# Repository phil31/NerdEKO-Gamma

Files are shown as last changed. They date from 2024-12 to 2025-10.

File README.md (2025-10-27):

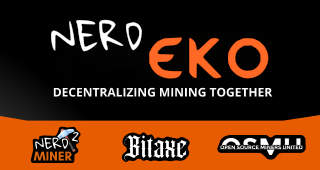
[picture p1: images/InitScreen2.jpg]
Nerd_EKO


# Nerd-EKO-Gamma Miner

fork of the NerdOCTAXE-Gamma design (https://github.com/Patsch91/NerdOCTAXE-Gamma), with 12 x BM1370 (14TH/s SHA256)
	
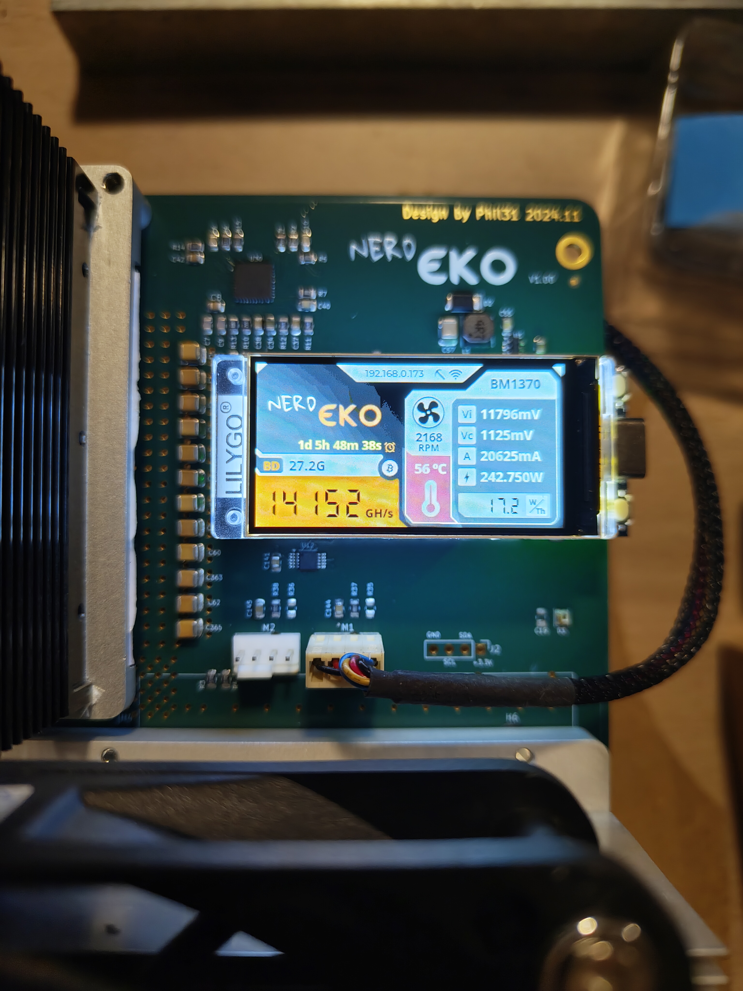
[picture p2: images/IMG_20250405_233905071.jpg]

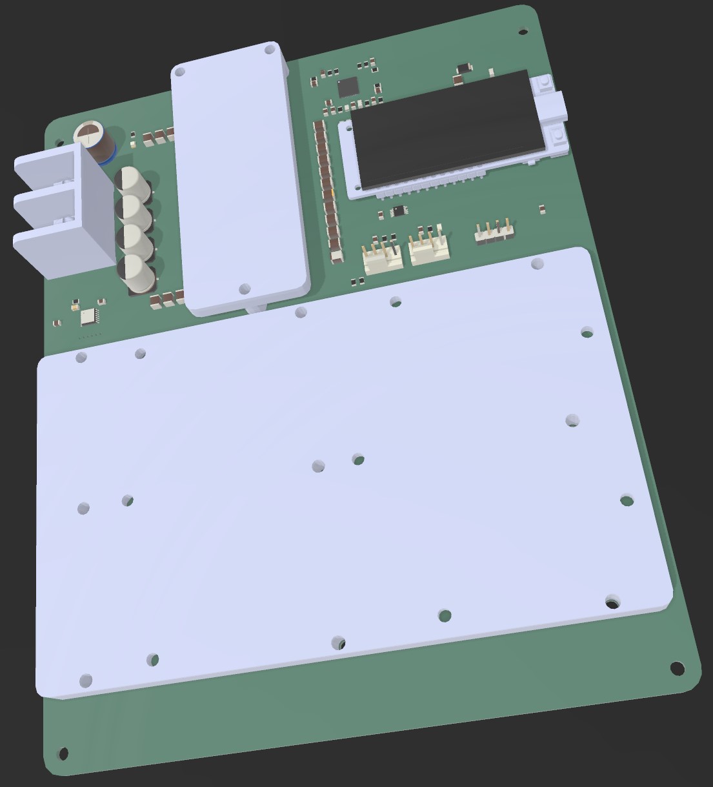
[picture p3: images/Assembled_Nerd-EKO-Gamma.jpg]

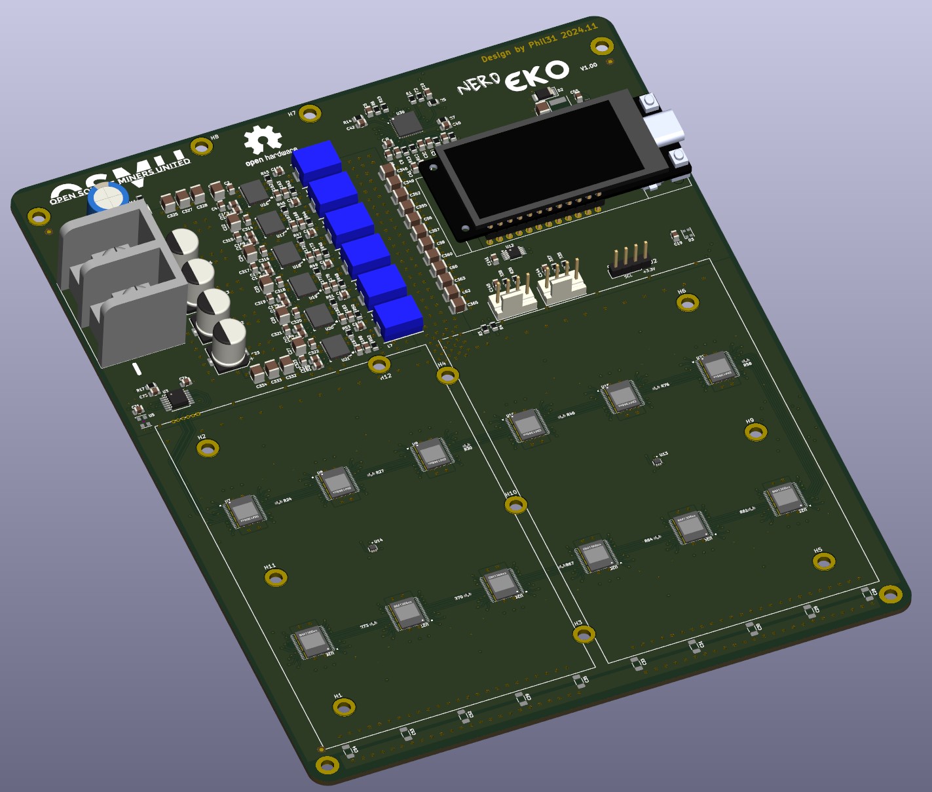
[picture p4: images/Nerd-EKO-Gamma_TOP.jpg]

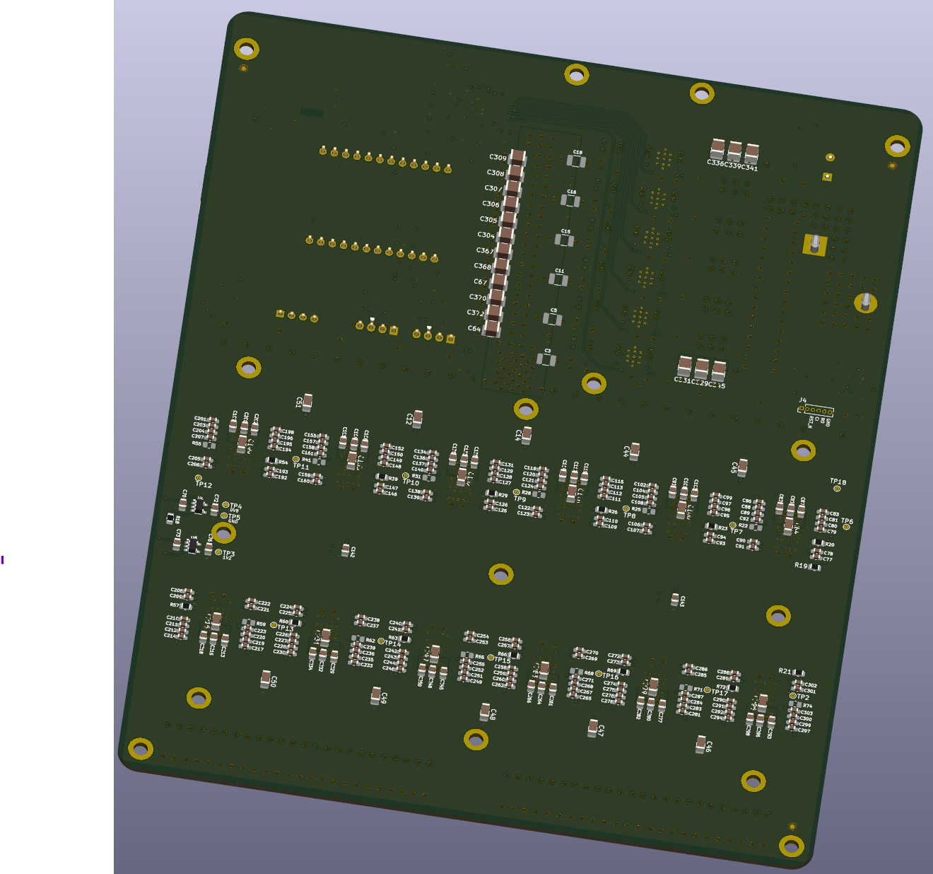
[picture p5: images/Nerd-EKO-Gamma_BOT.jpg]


- 6 layers PCB - Outer / Inner Copper Weight: 2 oz

Design fully tested and validated
consume about 230 Watts on 12V for about 14TH/s (Vcore 1100mV, Icore 180A)
use a 12V 40A PSU

be aware, need some knowledge and tools to build this board !
particulary attention : NEVER power up the board with the Vcore enable without proper heatsink (this will immediatly kill the ASICs !)

## License 
This hardware design is licensed under the TAPR Open Hardware License – Non-Commercial (OHL-NC).  
You are free to use, modify, and distribute for **non-commercial purposes**.  

**Commercial use requires explicit written permission from the copyright holder.**  
See the [LICENSE](LICENSE) file for details.

## Inspired by 
[Bitaxe](https://github.com/skot/bitaxe) 
[NerdAxe](https://github.com/BitMaker-hub)
[NerdOCTAXE](https://github.com/Patsch91/NerdOCTAXE-Gamma) 
[ESP-Miner-NerdQAxePlus](https://github.com/shufps/ESP-Miner-NerdQAxePlus)
[OSMU](https://osmu.wiki/)

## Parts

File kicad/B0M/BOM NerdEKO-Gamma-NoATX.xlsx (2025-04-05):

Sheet: BOM NerdEKO-Gamma-NoATX (2)
Reference | Value | Footprint | Qty | DNP | P/N MOUSER | P/N LCSC
C77,C78,C79,C80,C81,C83,C86,C88,C89,C90,C91,C92,C93,C94,C95,C96,C97,C99,C102,C104,C105,C106,C107,C108,C109,C110,C111,C112,C113,C115,C118,C120,C121,C122,C123,C124,C125,C126,C127,C128,C129,C131,C134,C136,C137,C138,C139,C140,C146,C147,C148,C149,C150,C152,C155,C157,C158,C159,C160,C161,C192,C193,C194,C195,C196,C198,C201,C203,C204,C205,C206,C207,C208,C209,C210,C211,C212,C214,C217,C219,C220,C221,C222,C223,C224,C225,C226,C227,C228,C230,C233,C235,C236,C237,C238,C239,C240,C241,C242,C243,C244,C246,C249,C251,C252,C253,C254,C255,C256,C257,C258,C259,C260,C262,C265,C267,C268,C269,C270,C271,C272,C273,C274,C275,C276,C278,C281,C283,C284,C285,C286,C287,C288,C289,C290,C291,C292,C294,C297,C299,C300,C301,C302,C303 | 1µF/6.3V | Capacitor_SMD:C_0603_1608Metric_Pad1.08x0.95mm_HandSolder | 144 |  | 187-CL10A105KQ8NNNC | C105524
C2,C19,C21,C70,C71,C73,C74,C75,C87,C103,C119,C135,C141,C142,C143,C144,C145,C156,C162,C164,C167,C169,C172,C174,C177,C179,C182,C184,C187,C189,C202,C218,C234,C250,C266,C282,C298,C314,C316,C318,C320,C322 | 100nF | Capacitor_SMD:C_0805_2012Metric | 42 |  | 791-0805B104M101CT | C476766
C4,C37,C38,C72,C76,C85,C101,C117,C133,C154,C200,C216,C232,C248,C264,C280,C296,C315,C317,C319,C321,C323 | 1µF/25V | Capacitor_SMD:C_0805_2012Metric | 22 |  | 187-CL21B105KAFNNNE | C344171
C6,C10,C43,C165,C166,C170,C171,C175,C176,C180,C181,C185,C186,C190,C191 | 1nF | Capacitor_SMD:C_0805_2012Metric | 15 |  | 603-CC805KRX7R0BB102 | C106244
C7,C9 | 22pF | Capacitor_SMD:C_0805_2012Metric | 2 |  | 187-CL21C220JBANNNC | C1804
C8 | 100pF | Capacitor_SMD:C_0805_2012Metric | 1 |  | 791-0805B101M250CT | C3897824
C13,C17,C82,C98,C114,C130,C151,C197,C213,C229,C245,C261,C277,C293 | 10µF/25V | Capacitor_SMD:C_0805_2012Metric | 14 |  | 963-TMK212BBJ106MG-T | C6119887
C34 | 4.7µF/16V | Capacitor_SMD:C_0805_2012Metric | 1 |  | 187-CL21A475KOFNNNG | C22399642
C40 | 330nF | Capacitor_SMD:C_0805_2012Metric | 1 |  | 187-CL21B334KBFNNNE | C73142
C41 | 12pF | Capacitor_SMD:C_0805_2012Metric | 1 |  | 581-KGM15ACG2A120JM | C20218205
C42 | 2.2nF | Capacitor_SMD:C_0805_2012Metric | 1 |  | 791-0805B222K160CT | C3907092
C55 | 10nF | Capacitor_SMD:C_0805_2012Metric | 1 |  | 187-CL21B103KBANNNC | C1710
C163,C168,C173,C178,C183,C188 | 2.2µF/16V | Capacitor_SMD:C_0805_2012Metric | 6 |  | 187-CL21A225KOFNNNE | C5448893
C12,C14,C44,C45,C46,C47,C48,C49,C50,C51,C84,C100,C116,C132,C153,C199,C215,C231,C247,C263,C279,C295 | 100µ/6.3V | Capacitor_SMD:C_1206_3216Metric | 22 |  | 187-CL31A107MQHNNWE | C15008
C28,C29,C30,C31,C33,C35,C39,C52,C53,C54 | 100µ/6.3V | Capacitor_SMD:C_1206_3216Metric | 10 | DNP | 187-CL31A107MQHNNWE | C15008
C3,C5,C11,C15,C16,C18 | 330µF/4V | Capacitor_SMD:C_1210_3225Metric | 6 | DNP | 81-GRM32ER60G337ME5K | C528969
C20,C22,C24,C25,C26,C27,C57,C325,C327,C328,C329,C331,C332,C333,C334,C336,C339,C341,C345 | 22µ/25V | Capacitor_SMD:C_1210_3225Metric | 19 |  | 187-CL32A226KAJNNNE | C52306
C56,C58,C60,C62,C64,C67,C304,C305,C306,C307,C308,C309,C346,C349,C352,C355,C357,C360,C363,C365,C367,C368,C370,C372 | 330µF/4V | Capacitor_SMD:C_1210_3225Metric | 24 |  | 81-GRM32ER60G337ME5K | C528969
C23,C32,C36,C313 | 470µ/25V | Capacitor_SMD:CP_Elec_8x10 | 4 |  | 647-UWT1E471MNL1S | C4054389
C1 | 1000uF/25V | Capacitor_THT:CP_Radial_D10.0mm_P5.00mm | 1 |  | 667-EEU-FR1E102L | C2980548
M1,M2 | Fan_4pin | Connector:FanPinHeader_1x04_P2.54mm_Vertical | 2 |  | 538-47053-1000 | C240840
J2 | Conn_01x04 | Connector_PinHeader_2.54mm:PinHeader_1x04_P2.54mm_Vertical | 1 | DNP
D2 | PMEG4030EP,115 | Diode_SMD:D_SOD-128 | 1 |  | 771-PMEG4030EP-QX | C96234
U7,U8,U9,U10,U15,U22,U23,U24,U25,U26,U27,U28 | BM1370_mode1 | EKO_Miner_ASIClib:BM1370 | 12
U16,U17,U18,U19,U20,U21 | CSD95472Q5MC | EKO_Miner_ASIClib:CSD95472Q5MC | 6 |  | 595-CSD95472Q5MC | C1880674
L2,L3,L4,L5,L6,L7 | 220nH | EKO_Miner_ASIClib:INDM1031X765N | 6 |  | 504-FP1008R5-R220-R | C2639748
U11 | T-Display-S3 | EKO_Miner_ASIClib:LILYGO Tdisplay S3 | 1
J1 | Conn_01x02 | EKO_Miner_ASIClib:MOLEX_38969-0002 | 1 |  | 538-38969-0002 | C7426780
U13,U14 | TMP1075NDRLR | EKO_Miner_ASIClib:SOT50P160X60-6N | 2 |  | 595-TMP1075NDRLR | C3663690
U30 | TPS53667RTAR | EKO_Miner_ASIClib:TPS53667RTAR | 1 |  | 595-TPS53667RTAT | C702270
L1 | 4.7µH | Inductor_SMD:L_Taiyo-Yuden_NR-50xx | 1 |  | 710-74404052047 | C703747
D1 | LED | LED_SMD:LED_0805_2012Metric_Pad1.15x1.40mm_HandSolder | 1 |  | 859-LTST-C171GKT | C913075
D3 | WS2812B-2020 | LED_SMD:LED_WS2812B-2020_PLCC4_2.0x2.0mm | 1 |  | 485-4684 | C965555
U5 | 25MHz | Oscillator:Oscillator_SMD_EuroQuartz_XO32-4Pin_3.2x2.5mm | 1 |  | 449-LFSPXO076024CUTT | C17671752
U12 | EMC2302-1 | Package_SO:MSOP-10_3x3mm_P0.5mm | 1 |  | 886-EMC2302-1-AIZLTR | C626969
U3 | TXU0304PW | Package_SO:TSSOP-14-1EP_4.4x5mm_P0.65mm | 1 |  | 595-TXU0304PWR | C4364118
U4 | MCP1824T-0802E | Package_TO_SOT_SMD:SOT-23-5 | 1 |  | 579-MCP1824T-0802EOT | C625460
U6 | MCP1824T-1202E | Package_TO_SOT_SMD:SOT-23-5 | 1 |  | 579-MCP1824T-1202EOT | C625461
U1 | AP3211 | Package_TO_SOT_SMD:SOT-23-6 | 1 |  | 621-AP3211KTR-G1 | C154863
R24,R27,R30,R40,R58,R61,R64,R67,R70,R73,R76 | 33R | Resistor_SMD:R_0402_1005Metric_Pad0.72x0.64mm_HandSolder | 11 |  | 652-CR0402FX-33R0GLF | C102986
R1,R9 | 16.5K | Resistor_SMD:R_0805_2012Metric | 2 |  | 603-RC0805FR-0716K5L | C35929
R2 | 24.3K | Resistor_SMD:R_0805_2012Metric | 1 |  | 603-RC0805FR-0724K3L | C17569
R3,R4 | 51 0.5% | Resistor_SMD:R_0805_2012Metric | 2 |  | 603-RT0805DRE0751RL | C868849
R5,R7,R17,R18,R19,R21,R32,R35,R36 | 10K | Resistor_SMD:R_0805_2012Metric | 9 |  | 279-CRGCQ0805F10K | C84376
R6 | 121K | Resistor_SMD:R_0805_2012Metric | 1 |  | 603-RT0805FRE07121KL | C17438
R8 | 86.6K | Resistor_SMD:R_0805_2012Metric | 1 |  | 652-CR0805FX-8662ELF | C17846
R10 | 2.55K | Resistor_SMD:R_0805_2012Metric | 1 |  | 667-ERJ-P06F2551V | C2933383
R11,R12 | 2.2R | Resistor_SMD:R_0805_2012Metric | 2 |  | 708-RMCF0805FT2R20 | C17521
R13 | 8.06K | Resistor_SMD:R_0805_2012Metric | 1 |  | 603-RC0805FR-078K06L | C2933501
R14 | 33.2K | Resistor_SMD:R_0805_2012Metric | 1 |  | 708-RMCF0805FT33K2 | C3016779
R15 | 100K | Resistor_SMD:R_0805_2012Metric | 1 |  | 279-CRG0805F100K | C149504
R16,R20,R23,R26,R29,R39,R54,R57,R60,R63,R66,R69,R72 | 1K | Resistor_SMD:R_0805_2012Metric | 13 |  | 708-RNCP0805FTD1K00 | C17513
R22,R25,R28,R31,R41,R56,R59,R62,R65,R68,R71,R74 | 2K | Resistor_SMD:R_0805_2012Metric | 12 | DNP | 652-CR0805FX-2001ELF | C17604
R33,R34 | 10K | Resistor_SMD:R_0805_2012Metric | 2 | DNP | 279-CRGCQ0805F10K | C84376
R37,R38 | 2.7K | Resistor_SMD:R_0805_2012Metric | 2 |  | 652-CR0805FX-2701ELF | C2907236
R42,R43,R44,R45,R46,R47,R48,R49,R50,R51,R52,R53 | 1R | Resistor_SMD:R_0805_2012Metric | 12 |  | 791-WR08W1R00FTL | C163970
TP2,TP3,TP4,TP5,TP6,TP7,TP8,TP9,TP10,TP11,TP12,TP13,TP14,TP15,TP16,TP17,TP18 | TestPoint | TestPoint:TestPoint_Pad_D1.0mm | 17 | DNP

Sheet: BOM NerdEKO-Gamma-NoATX
Reference,"Value","Footprint","Qty","DNP","P/N MOUSER","P/N LCSC"
C77,C78,C79,C80,C81,C83,C86,C88,C89,C90,C91,C92,C93,C94,C95,C96,C97,C99,C102,C104,C105,C106,C107,C108,C109,C110,C111,C112,C113,C115,C118,C120,C121,C122,C123,C124,C125,C126,C127,C128,C129,C131,C134,C136,C137,C138,C139,C140,C146,C147,C148,C149,C150,C152,C155,C157,C158,C159,C160,C161,C192,C193,C194,C195,C196,C198,C201,C203,C204,C205,C206,C207,C208,C209,C210,C211,C212,C214,C217,C219,C220,C221,C222,C223,C224,C225,C226,C227,C228,C230,C233,C235,C236,C237,C238,C239,C240,C241,C242,C243,C244,C246,C249,C251,C252,C253,C254,C255,C256,C257,C258,C259,C260,C262,C265,C267,C268,C269,C270,C271,C272,C273,C274,C275,C276,C278,C281,C283,C284,C285,C286,C287,C288,C289,C290,C291,C292,C294,C297,C299,C300,C301,C302,C303,"1ÂµF/6.3V","Capacitor_SMD:C_0603_1608Metric_Pad1.08x0.95mm_HandSolder","144","","187-CL10A105KQ8NNNC","C105524"
C2,C19,C21,C70,C71,C73,C74,C75,C87,C103,C119,C135,C141,C142,C143,C144,C145,C156,C162,C164,C167,C169,C172,C174,C177,C179,C182,C184,C187,C189,C202,C218,C234,C250,C266,C282,C298,C314,C316,C318,C320,C322,"100nF","Capacitor_SMD:C_0805_2012Metric","42","","791-0805B104M101CT","C476766"
C4,C37,C38,C72,C76,C85,C101,C117,C133,C154,C200,C216,C232,C248,C264,C280,C296,C315,C317,C319,C321,C323,"1ÂµF/25V","Capacitor_SMD:C_0805_2012Metric","22","","187-CL21B105KAFNNNE","C344171"
C6,C10,C43,C165,C166,C170,C171,C175,C176,C180,C181,C185,C186,C190,C191,"1nF","Capacitor_SMD:C_0805_2012Metric","15","","603-CC805KRX7R0BB102","C106244"
C7,C9,"22pF","Capacitor_SMD:C_0805_2012Metric","2","","187-CL21C220JBANNNC","C1804"
C8,"100pF","Capacitor_SMD:C_0805_2012Metric","1","","791-0805B101M250CT","C3897824"
C13,C17,C82,C98,C114,C130,C151,C197,C213,C229,C245,C261,C277,C293,"10ÂµF/25V","Capacitor_SMD:C_0805_2012Metric","14","","963-TMK212BBJ106MG-T","C6119887"
C34,"4.7ÂµF/16V","Capacitor_SMD:C_0805_2012Metric","1","","187-CL21A475KOFNNNG","C22399642"
C40,"330nF","Capacitor_SMD:C_0805_2012Metric","1","","187-CL21B334KBFNNNE","C73142"
C41,"12pF","Capacitor_SMD:C_0805_2012Metric","1","","581-KGM15ACG2A120JM","C20218205"
C42,"2.2nF","Capacitor_SMD:C_0805_2012Metric","1","","791-0805B222K160CT","C3907092"
C55,"10nF","Capacitor_SMD:C_0805_2012Metric","1","","187-CL21B103KBANNNC","C1710"
C163,C168,C173,C178,C183,C188,"2.2ÂµF/16V","Capacitor_SMD:C_0805_2012Metric","6","","187-CL21A225KOFNNNE","C5448893"
C12,C14,C44,C45,C46,C47,C48,C49,C50,C51,C84,C100,C116,C132,C153,C199,C215,C231,C247,C263,C279,C295,"100Âµ/6.3V","Capacitor_SMD:C_1206_3216Metric","22","","187-CL31A107MQHNNWE","C15008"
C28,C29,C30,C31,C33,C35,C39,C52,C53,C54,"100Âµ/6.3V","Capacitor_SMD:C_1206_3216Metric","10","DNP","187-CL31A107MQHNNWE","C15008"
C3,C5,C11,C15,C16,C18,"330ÂµF/4V","Capacitor_SMD:C_1210_3225Metric","6","DNP","81-GRM32ER60G337ME5K","C528969"
C20,C22,C24,C25,C26,C27,C57,C325,C327,C328,C329,C331,C332,C333,C334,C336,C339,C341,C345,"22Âµ/25V","Capacitor_SMD:C_1210_3225Metric","19","","187-CL32A226KAJNNNE","C52306"
C56,C58,C60,C62,C64,C67,C304,C305,C306,C307,C308,C309,C346,C349,C352,C355,C357,C360,C363,C365,C367,C368,C370,C372,"330ÂµF/4V","Capacitor_SMD:C_1210_3225Metric","24","","81-GRM32ER60G337ME5K","C528969"
C23,C32,C36,C313,"470Âµ/25V","Capacitor_SMD:CP_Elec_8x10","4","","647-UWT1E471MNL1S","C4054389"
C1,"1000uF/25V","Capacitor_THT:CP_Radial_D10.0mm_P5.00mm","1","","667-EEU-FR1E102L","C2980548"
M1,M2,"Fan_4pin","Connector:FanPinHeader_1x04_P2.54mm_Vertical","2","","538-47053-1000","C240840"
J2,"Conn_01x04","Connector_PinHeader_2.54mm:PinHeader_1x04_P2.54mm_Vertical","1","DNP","",""
D2,"PMEG4030EP,115","Diode_SMD:D_SOD-128","1","","771-PMEG4030EP-QX","C96234"
U7,U8,U9,U10,U15,U22,U23,U24,U25,U26,U27,U28,"BM1370_mode1","EKO_Miner_ASIClib:BM1370","12","","",""
U16,U17,U18,U19,U20,U21,"CSD95472Q5MC","EKO_Miner_ASIClib:CSD95472Q5MC","6","","595-CSD95472Q5MC","C1880674"
L2,L3,L4,L5,L6,L7,"220nH","EKO_Miner_ASIClib:INDM1031X765N","6","","504-FP1008R5-R220-R","C2639748"
U11,"T-Display-S3","EKO_Miner_ASIClib:LILYGO Tdisplay S3","1","","",""
J1,"Conn_01x02","EKO_Miner_ASIClib:MOLEX_38969-0002","1","","538-38969-0002","C7426780"
U13,U14,"TMP1075NDRLR","EKO_Miner_ASIClib:SOT50P160X60-6N","2","","595-TMP1075NDRLR","C3663690"
U30,"TPS53667RTAR","EKO_Miner_ASIClib:TPS53667RTAR","1","","595-TPS53667RTAT","C702270"
L1,"4.7ÂµH","Inductor_SMD:L_Taiyo-Yuden_NR-50xx","1","","710-74404052047","C703747"
D1,"LED","LED_SMD:LED_0805_2012Metric_Pad1.15x1.40mm_HandSolder","1","","859-LTST-C171GKT","C913075"
D3,"WS2812B-2020","LED_SMD:LED_WS2812B-2020_PLCC4_2.0x2.0mm","1","","485-4684","C965555"
U5,"25MHz","Oscillator:Oscillator_SMD_EuroQuartz_XO32-4Pin_3.2x2.5mm","1","","449-LFSPXO076024CUTT","C17671752"
U12,"EMC2302-1","Package_SO:MSOP-10_3x3mm_P0.5mm","1","","886-EMC2302-1-AIZLTR","C626969"
U3,"TXU0304PW","Package_SO:TSSOP-14-1EP_4.4x5mm_P0.65mm","1","","595-TXU0304PWR","C4364118"
U4,"MCP1824T-0802E","Package_TO_SOT_SMD:SOT-23-5","1","","579-MCP1824T-0802EOT","C625460"
U6,"MCP1824T-1202E","Package_TO_SOT_SMD:SOT-23-5","1","","579-MCP1824T-1202EOT","C625461"
U1,"AP3211","Package_TO_SOT_SMD:SOT-23-6","1","","621-AP3211KTR-G1","C154863"
R24,R27,R30,R40,R58,R61,R64,R67,R70,R73,R76,"33R","Resistor_SMD:R_0402_1005Metric_Pad0.72x0.64mm_HandSolder","11","","652-CR0402FX-33R0GLF","C102986"
R1,R9,"16.5K","Resistor_SMD:R_0805_2012Metric","2","","603-RC0805FR-0716K5L","C35929"
R2,"24.3K","Resistor_SMD:R_0805_2012Metric","1","","603-RC0805FR-0724K3L","C17569"
R3,R4,"51 0.5%","Resistor_SMD:R_0805_2012Metric","2","","603-RT0805DRE0751RL","C868849"
R5,R7,R17,R18,R19,R21,R32,R35,R36,"10K","Resistor_SMD:R_0805_2012Metric","9","","279-CRGCQ0805F10K","C84376"
R6,"121K","Resistor_SMD:R_0805_2012Metric","1","","603-RT0805FRE07121KL","C17438"
R8,"86.6K","Resistor_SMD:R_0805_2012Metric","1","","652-CR0805FX-8662ELF","C17846"
R10,"2.55K","Resistor_SMD:R_0805_2012Metric","1","","667-ERJ-P06F2551V","C2933383"
R11,R12,"2.2R","Resistor_SMD:R_0805_2012Metric","2","","708-RMCF0805FT2R20","C17521"
R13,"8.06K","Resistor_SMD:R_0805_2012Metric","1","","603-RC0805FR-078K06L","C2933501"
R14,"33.2K","Resistor_SMD:R_0805_2012Metric","1","","708-RMCF0805FT33K2","C3016779"
R15,"100K","Resistor_SMD:R_0805_2012Metric","1","","279-CRG0805F100K ","C149504"
R16,R20,R23,R26,R29,R39,R54,R57,R60,R63,R66,R69,R72,"1K","Resistor_SMD:R_0805_2012Metric","13","","708-RNCP0805FTD1K00","C17513"
R22,R25,R28,R31,R41,R56,R59,R62,R65,R68,R71,R74,"2K","Resistor_SMD:R_0805_2012Metric","12","DNP","652-CR0805FX-2001ELF","C17604"
R33,R34,"10K","Resistor_SMD:R_0805_2012Metric","2","DNP","279-CRGCQ0805F10K","C84376"
R37,R38,"2.7K","Resistor_SMD:R_0805_2012Metric","2","","652-CR0805FX-2701ELF","C2907236"
R42,R43,R44,R45,R46,R47,R48,R49,R50,R51,R52,R53,"1R","Resistor_SMD:R_0805_2012Metric","12","","791-WR08W1R00FTL","C163970"
TP2,TP3,TP4,TP5,TP6,TP7,TP8,TP9,TP10,TP11,TP12,TP13,TP14,TP15,TP16,TP17,TP18,"TestPoint","TestPoint:TestPoint_Pad_D1.0mm","17","DNP","",""

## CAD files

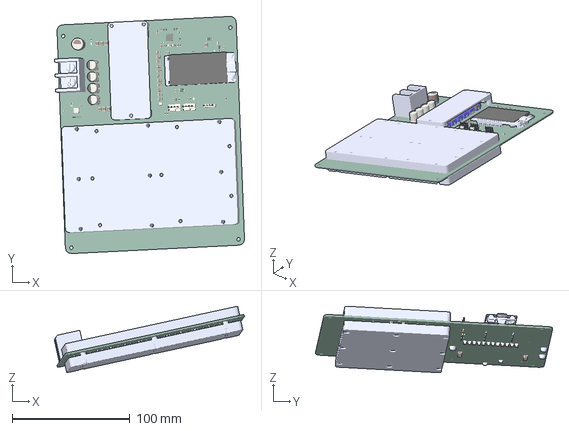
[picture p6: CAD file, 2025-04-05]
3D/Assemblage NerdEKO V1.0 with Heatsinks.3MF
161.3 x 201.3 x 56.3 mm

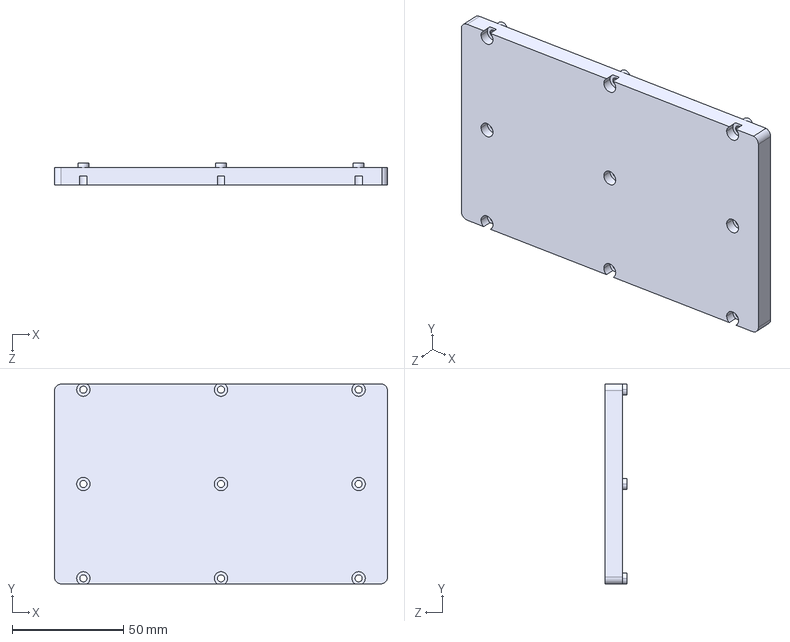
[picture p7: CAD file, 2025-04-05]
3D/EKO_Miner NerdEKO V1.0/Heatsink Nerd EKO - bottom ASICs V1.0.STEP
150.0 x 90.0 x 10.0 mm

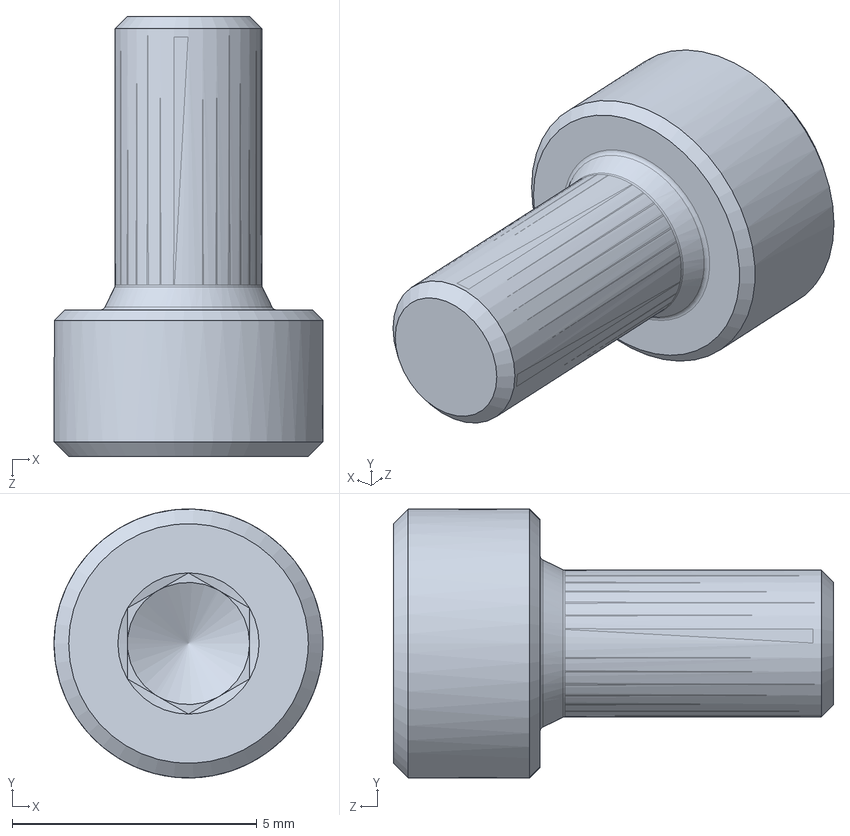
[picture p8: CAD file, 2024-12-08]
3D/quincaillerie/CHC3 M3x6mm.SLDPRT
5.50 x 5.50 x 9.00 mm

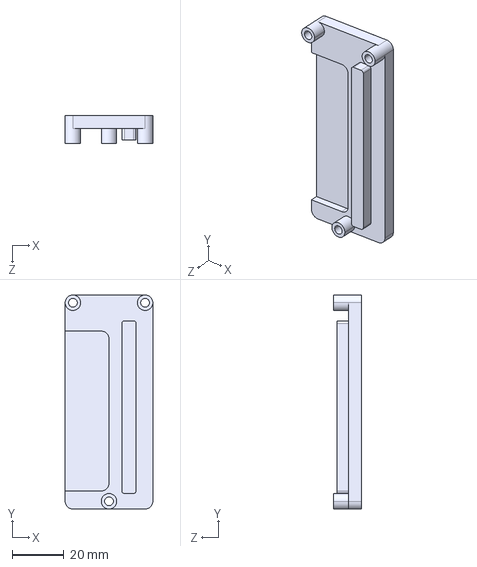
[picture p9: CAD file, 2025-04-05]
3D/EKO_Miner NerdEKO V1.0/Heatsink Nerd EKO - PSU V1.0.STEP
34.0 x 83.0 x 10.8 mm

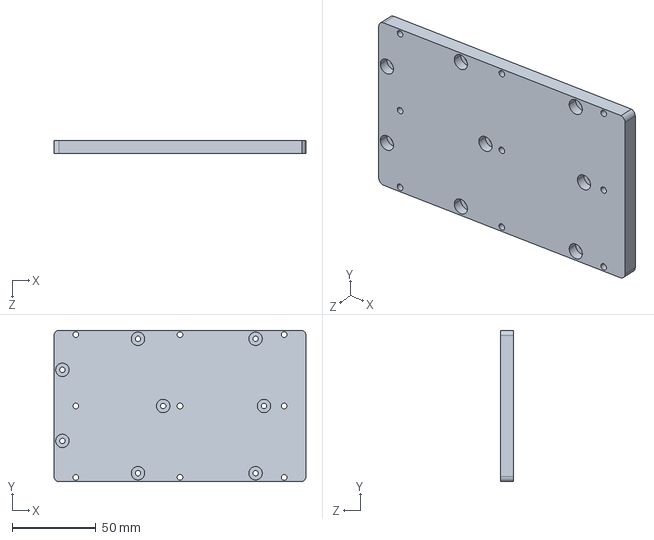
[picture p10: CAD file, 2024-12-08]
3D/EKO_Miner NerdEKO V1.0/Heatsink Nerd EKO - base ASICs V1.0.STEP
150.0 x 90.0 x 8.00 mm

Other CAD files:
3D/EKO_Miner NerdEKO V1.0/Heatsink Nerd EKO - PSU V1.0.SLDPRT
3D/EKO_Miner NerdEKO V1.0/Heatsink Nerd EKO - base ASICs V1.0.SLDPRT
3D/EKO_Miner NerdEKO V1.0/Heatsink Nerd EKO - bottom ASICs V1.0.SLDPRT

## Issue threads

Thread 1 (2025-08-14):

how to up 600Mhz

chenyang2151, 2025-08-14:
[

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

only 400mhz is the best，set uppon will 0v](url)

chenyang2151, 2025-08-14:
分析下具体会是什么原因导致的，非常感谢！爱你
参考知识
41/5000
Sorry, I was a bit anxious when I sent it. Could you please help me analyze the specific cause? Thank you very much! Love You

chenyang2151, 2025-08-14:
Sorry, I was a bit anxious when I sent it. Could you please help me analyze the specific cause? Thank you very much! Love You

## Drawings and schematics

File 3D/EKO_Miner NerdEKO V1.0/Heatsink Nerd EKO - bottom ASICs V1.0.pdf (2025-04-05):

E E

F F

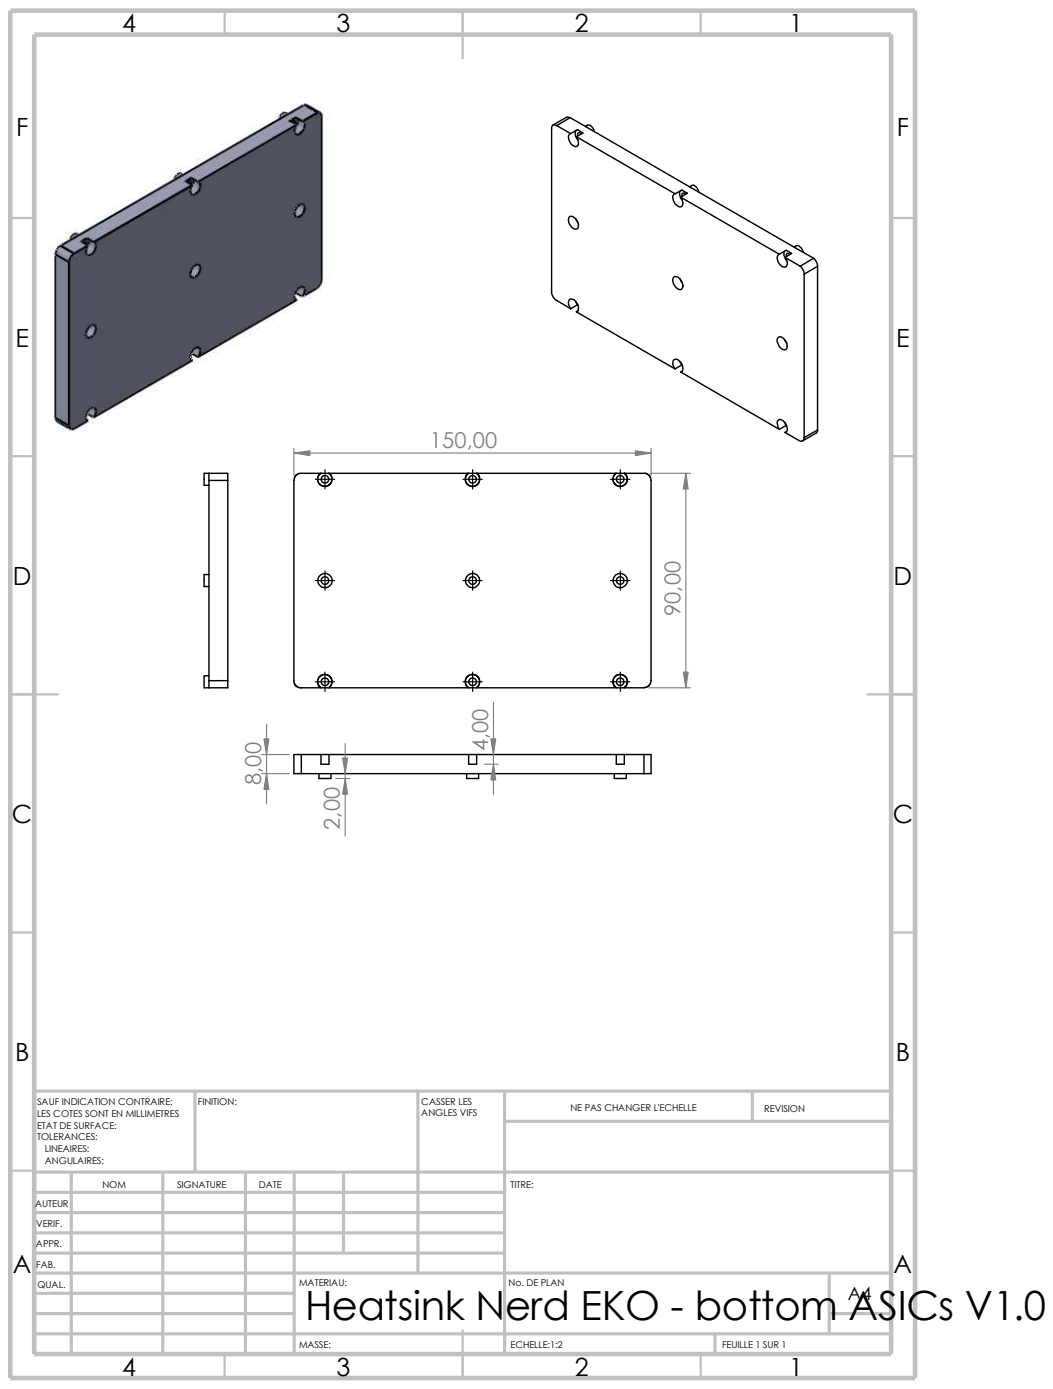
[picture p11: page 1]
MASSE:; FAB.; QUAL.; No. DE PLAN; ECHELLE:1:2; FEUILLE 1 SUR 1; FINITION:; ANGLES VIFS; MATERIAU:; NE PAS CHANGER L'ECHELLE; REVISION; CASSER LES; Heatsink Nerd EKO - bottom ASICs V1.0 ²,00 8,00

SAUF INDICATION CONTRAIRE:
LES COTES SONT EN MILLIMETRES
ETAT DE SURFACE:
TOLERANCES:
LINEAIRES:
ANGULAIRES:

NOM | SIGNATURE | DATE | TITRE:

AUTEUR
VERIF.
APPR.

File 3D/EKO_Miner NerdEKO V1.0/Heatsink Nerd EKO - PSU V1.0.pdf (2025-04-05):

E E

F F

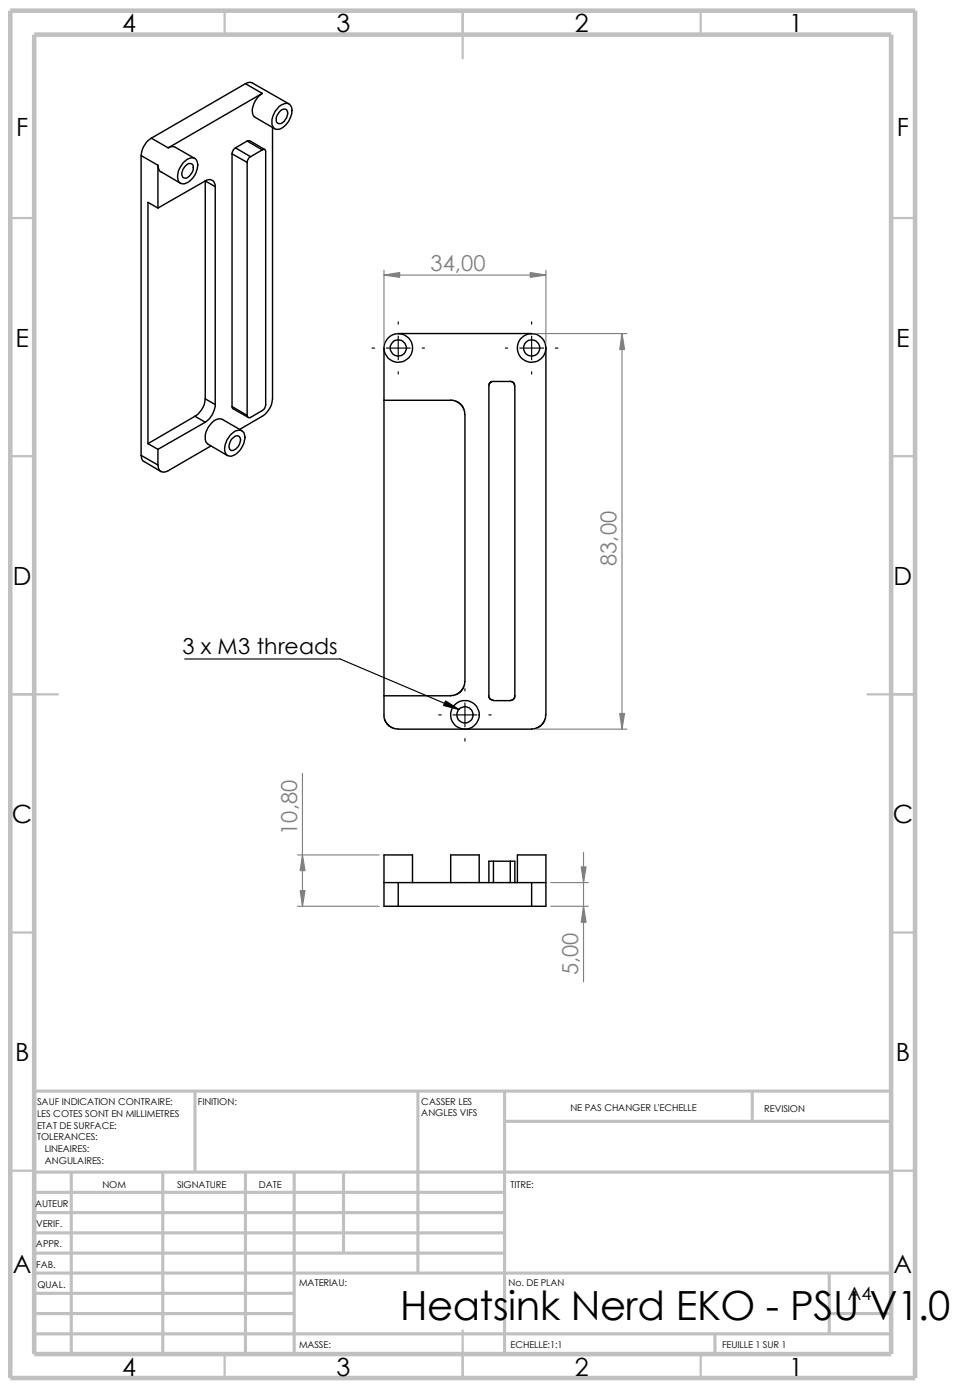
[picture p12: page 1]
MASSE:; ECHELLE:1:1; FEUILLE 1 SUR 1; NE PAS CHANGER L'ECHELLE; REVISION; FAB.; QUAL.; FINITION:; ANGLES VIFS; MATERIAU:; CASSER LES; 3 x M3 threads

SAUF INDICATION CONTRAIRE:
LES COTES SONT EN MILLIMETRES
ETAT DE SURFACE:
TOLERANCES:
LINEAIRES:
ANGULAIRES:

NOM | SIGNATURE | DATE | TITRE:

AUTEUR
VERIF.
APPR.

No. DE PLAN
Heatsink Nerd EKO - PSU V1.0

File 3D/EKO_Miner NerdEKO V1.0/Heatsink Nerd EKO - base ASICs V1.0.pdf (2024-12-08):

E E

F F

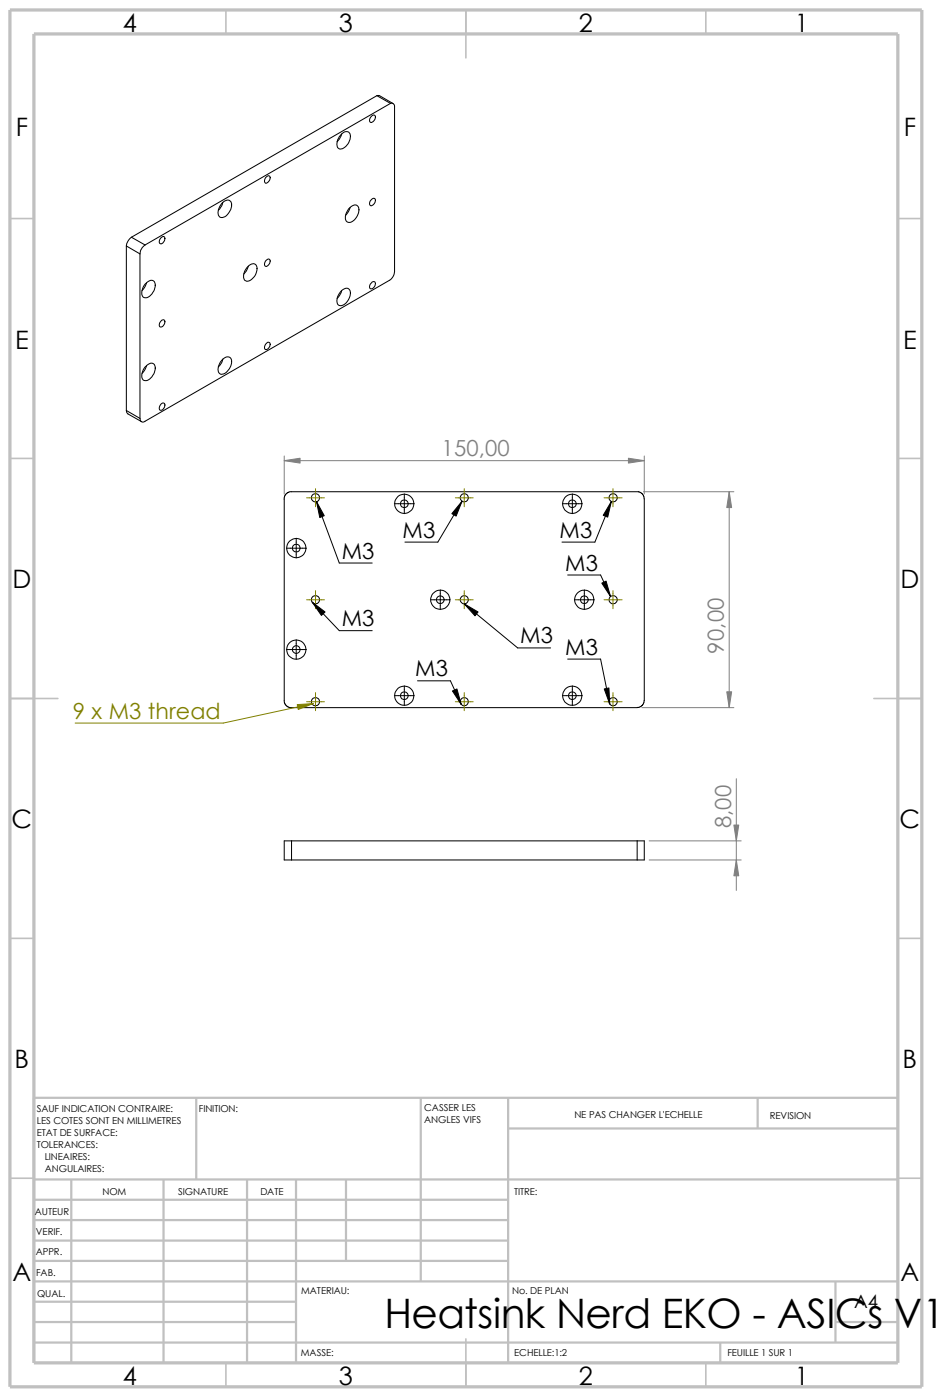
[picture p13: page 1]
FEUILLE 1 SUR 1; MASSE:; REVISION; MATERIAU:; ECHELLE:1:2; ANGLES VIFS; FAB.; QUAL.; FINITION:; CASSER LES; 9 x M3 thread

SAUF INDICATION CONTRAIRE:
LES COTES SONT EN MILLIMETRES
ETAT DE SURFACE:
TOLERANCES:
LINEAIRES:
ANGULAIRES:

NE PAS CHANGER L'ECHELLE

NOM | SIGNATURE | DATE | TITRE:

AUTEUR
VERIF.
APPR.

No. DE PLAN
Heatsink Nerd EKO - ASICs V1.0

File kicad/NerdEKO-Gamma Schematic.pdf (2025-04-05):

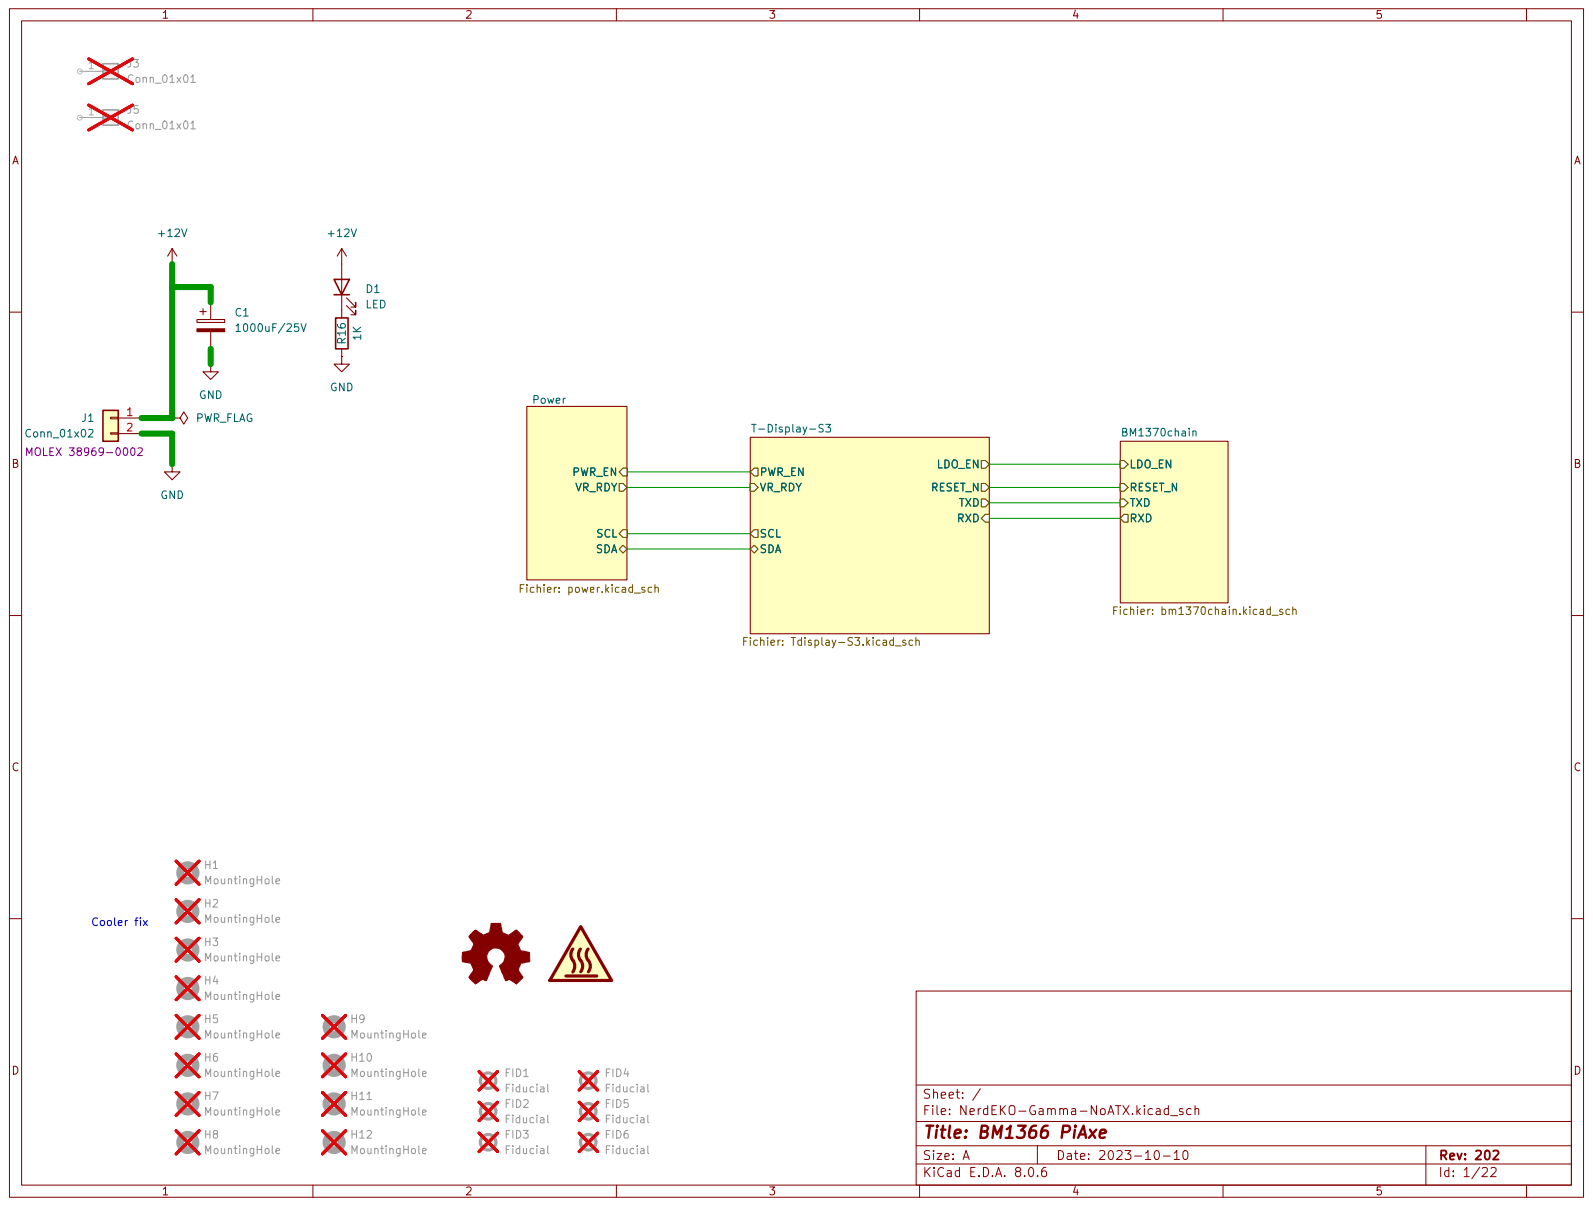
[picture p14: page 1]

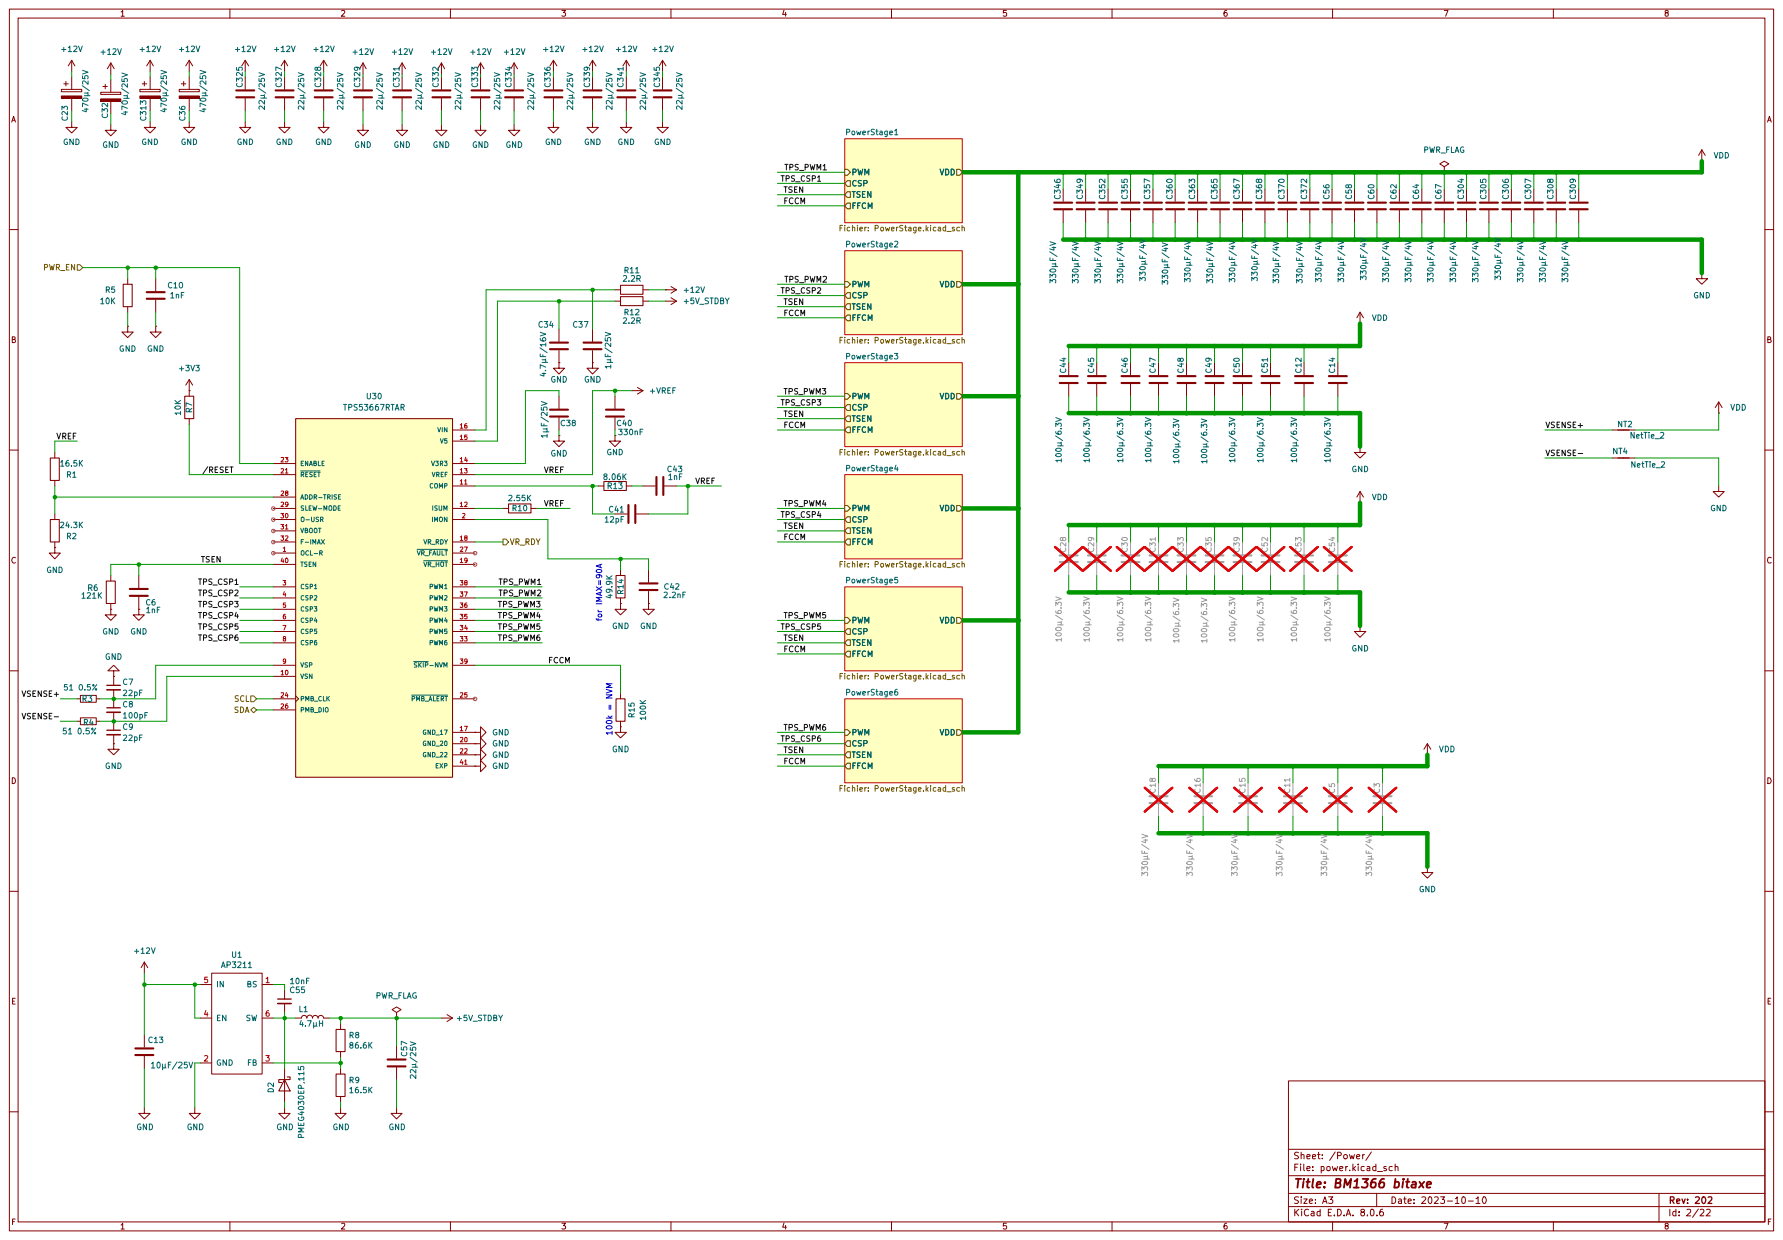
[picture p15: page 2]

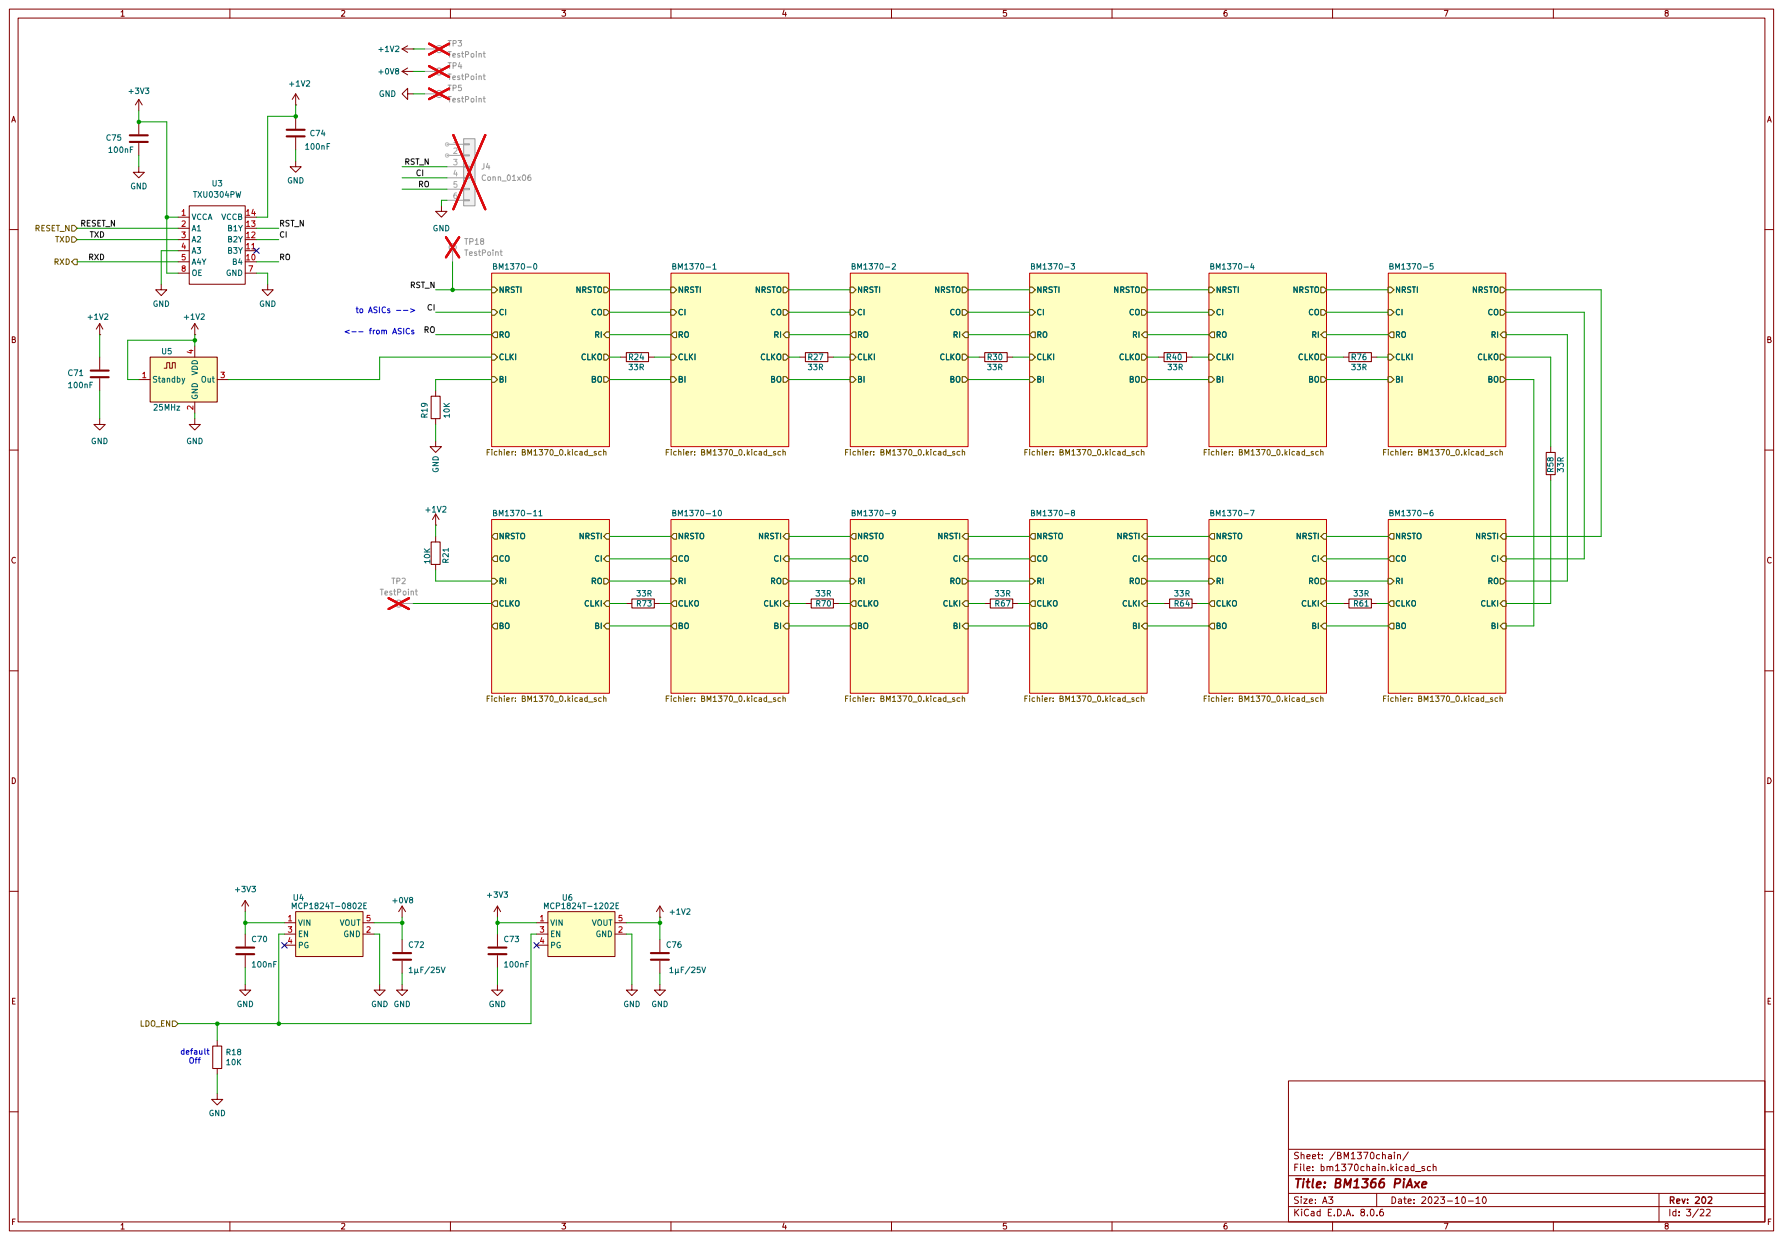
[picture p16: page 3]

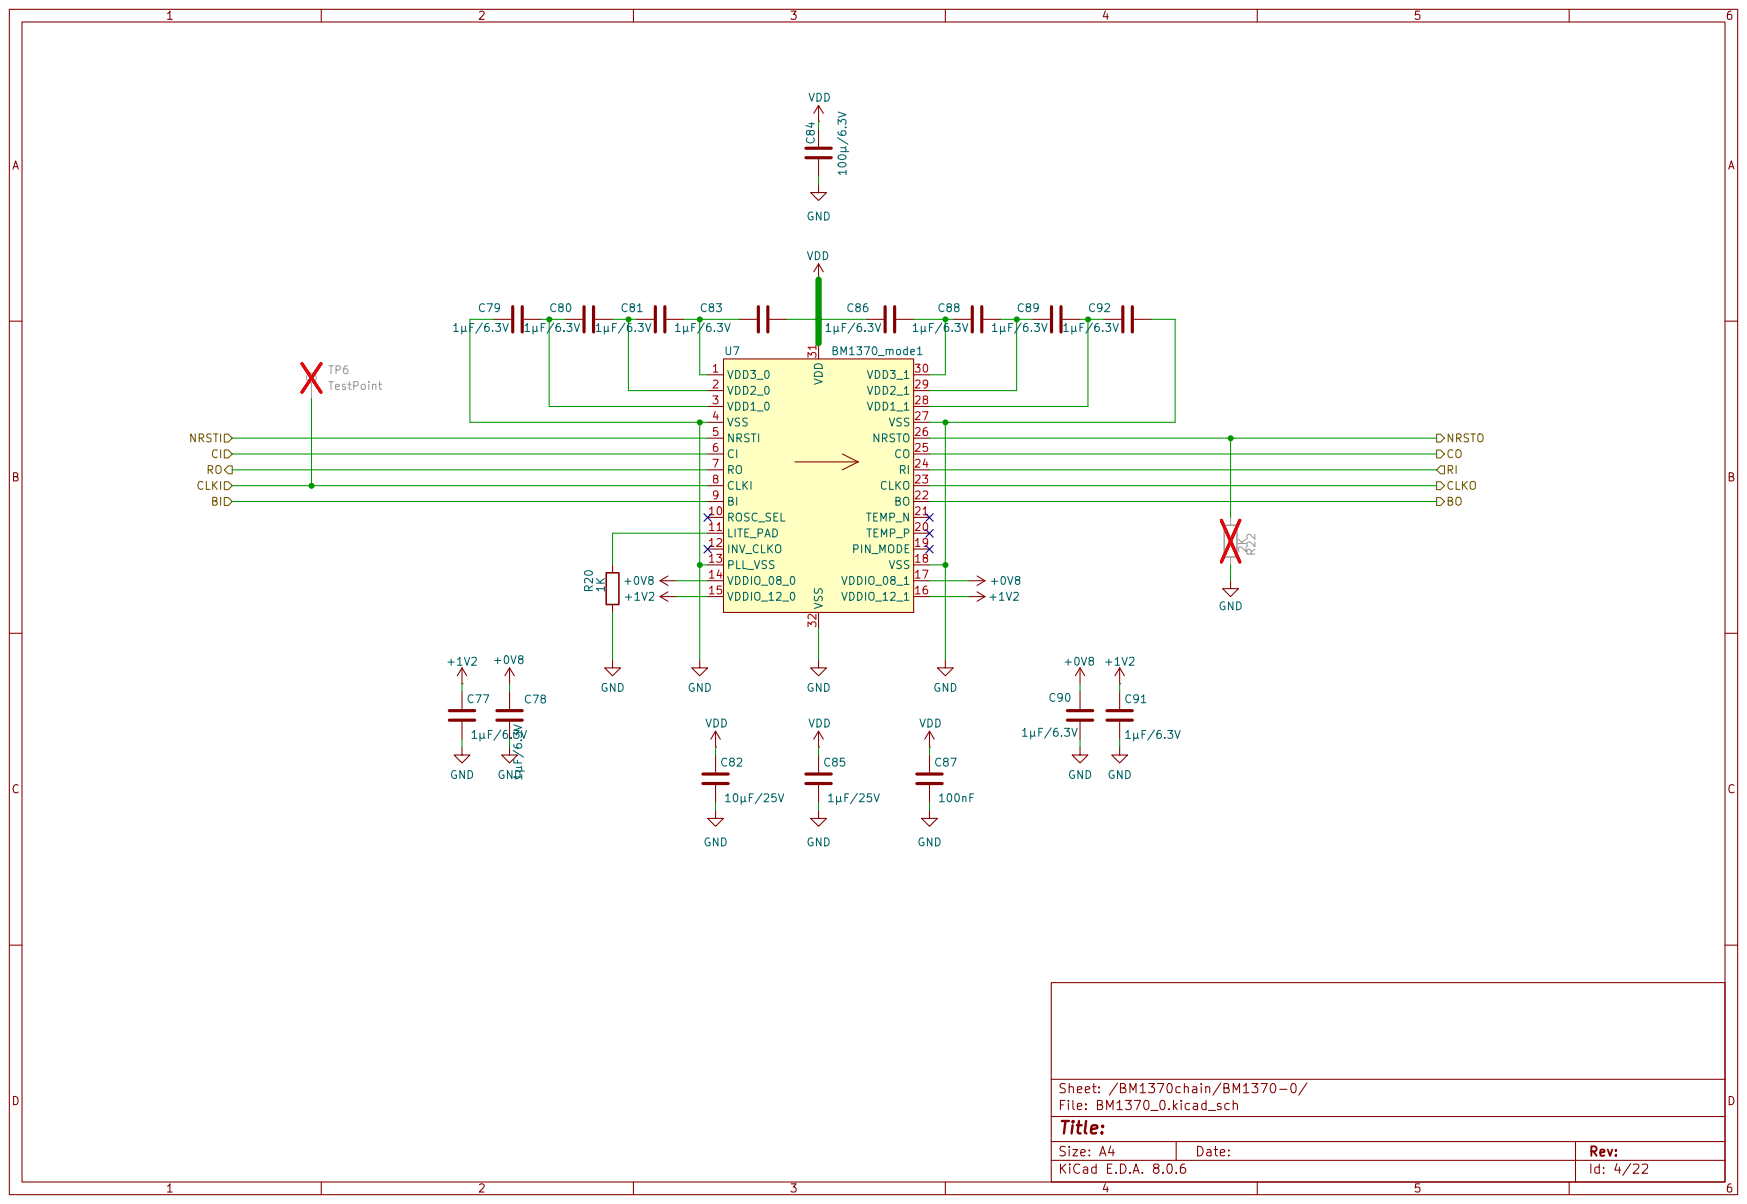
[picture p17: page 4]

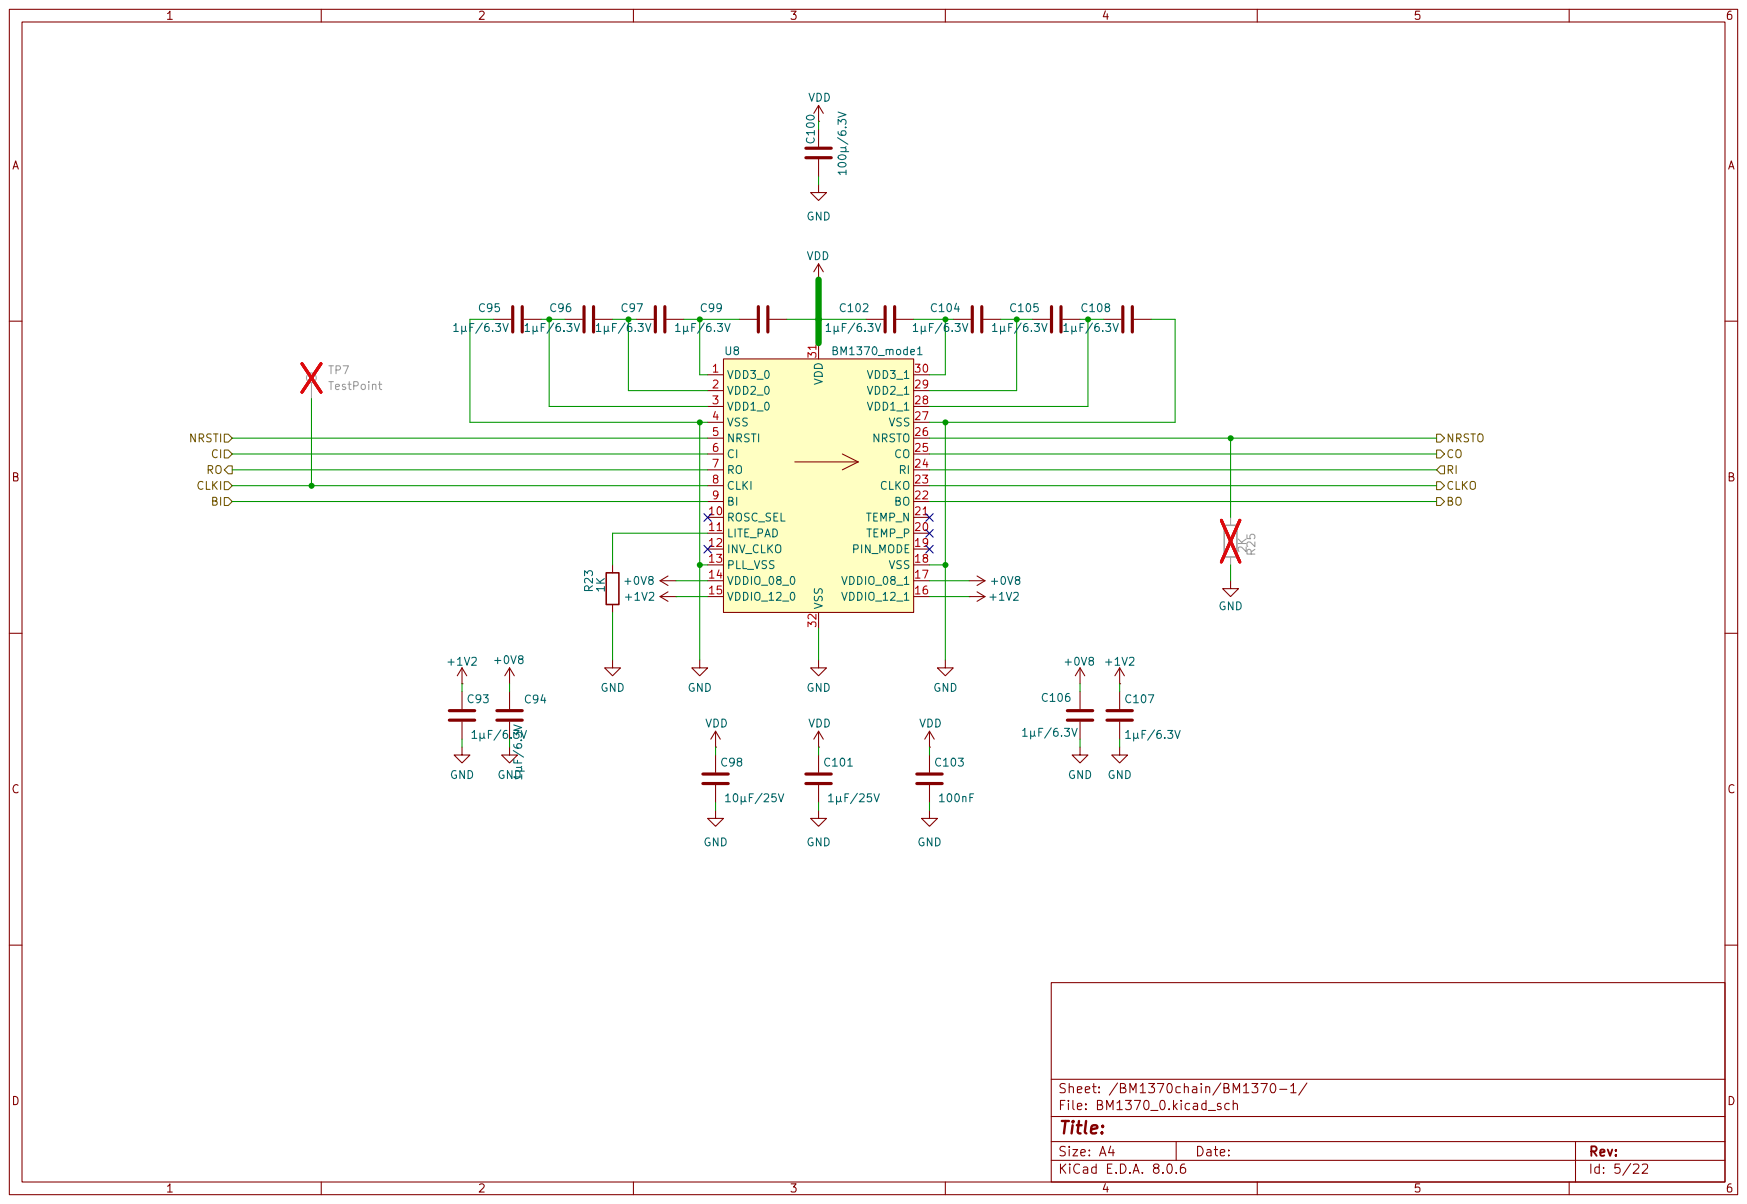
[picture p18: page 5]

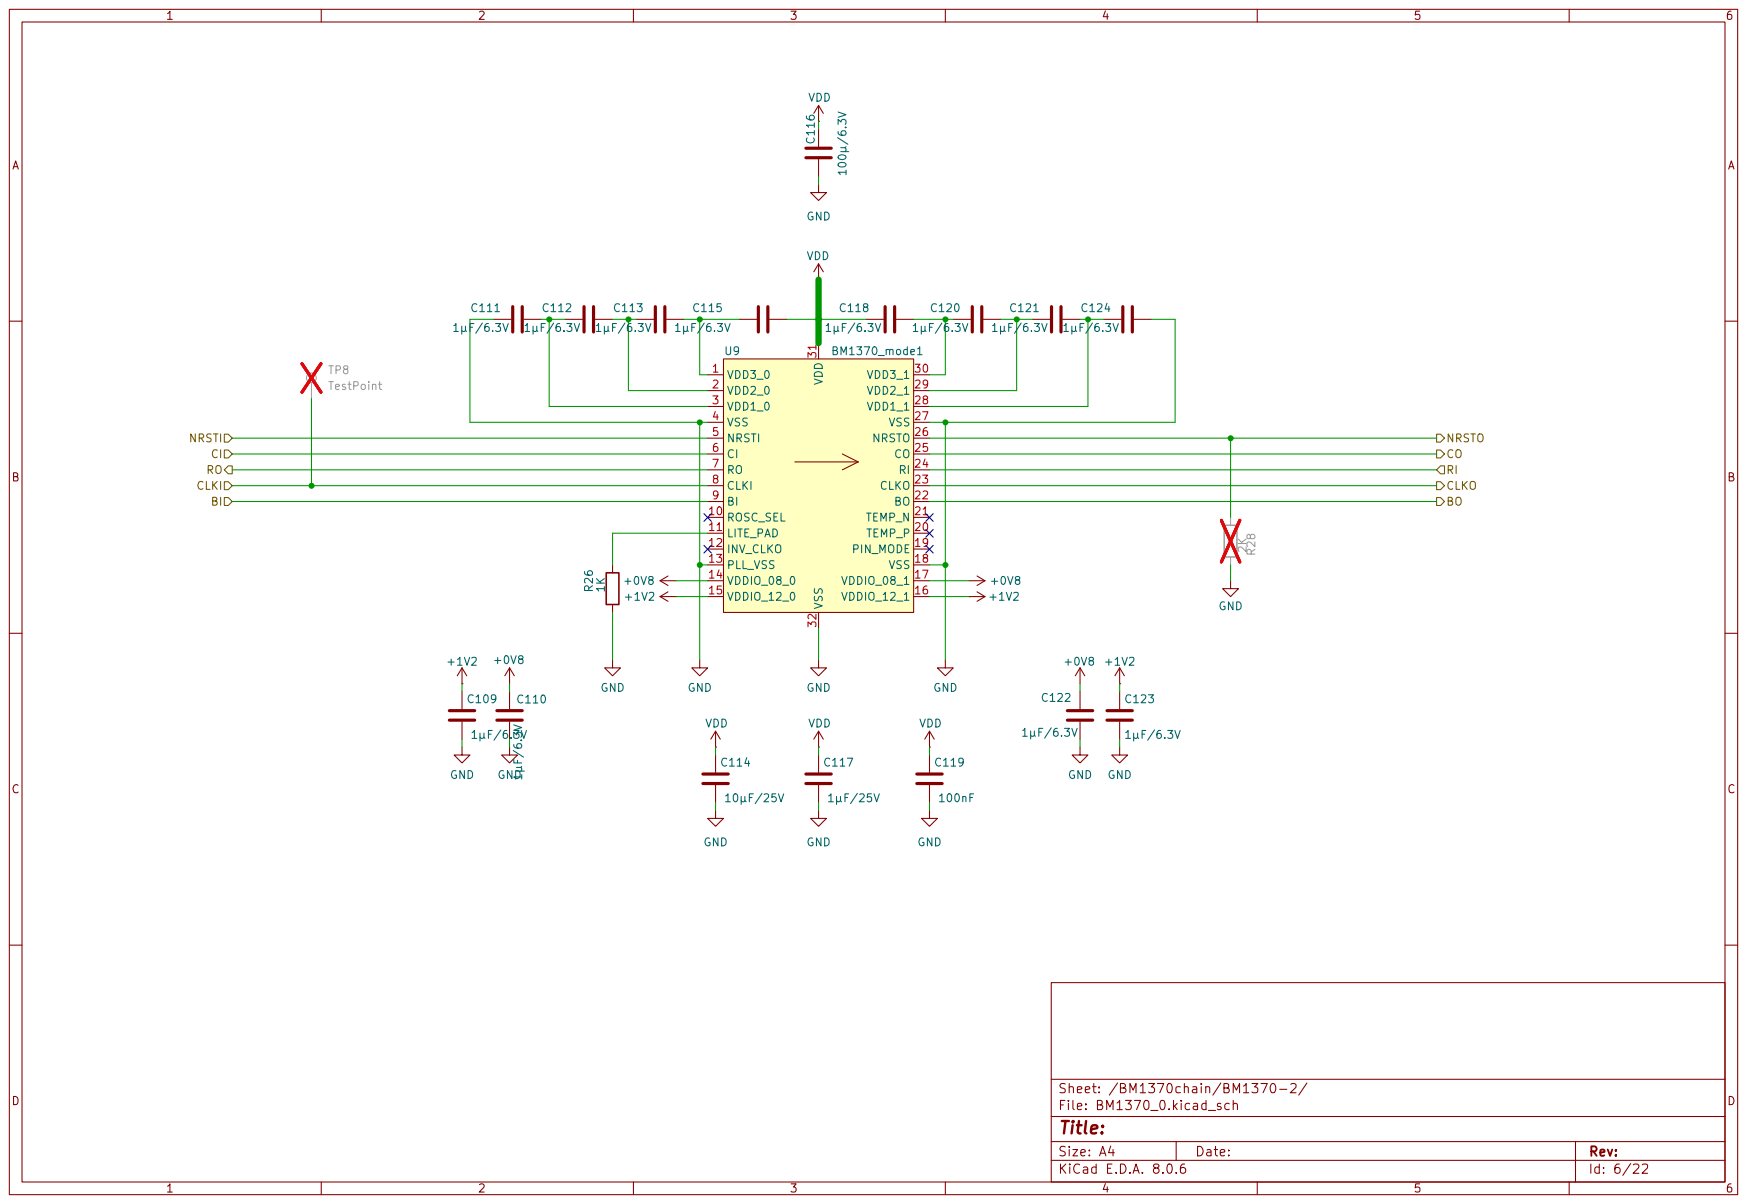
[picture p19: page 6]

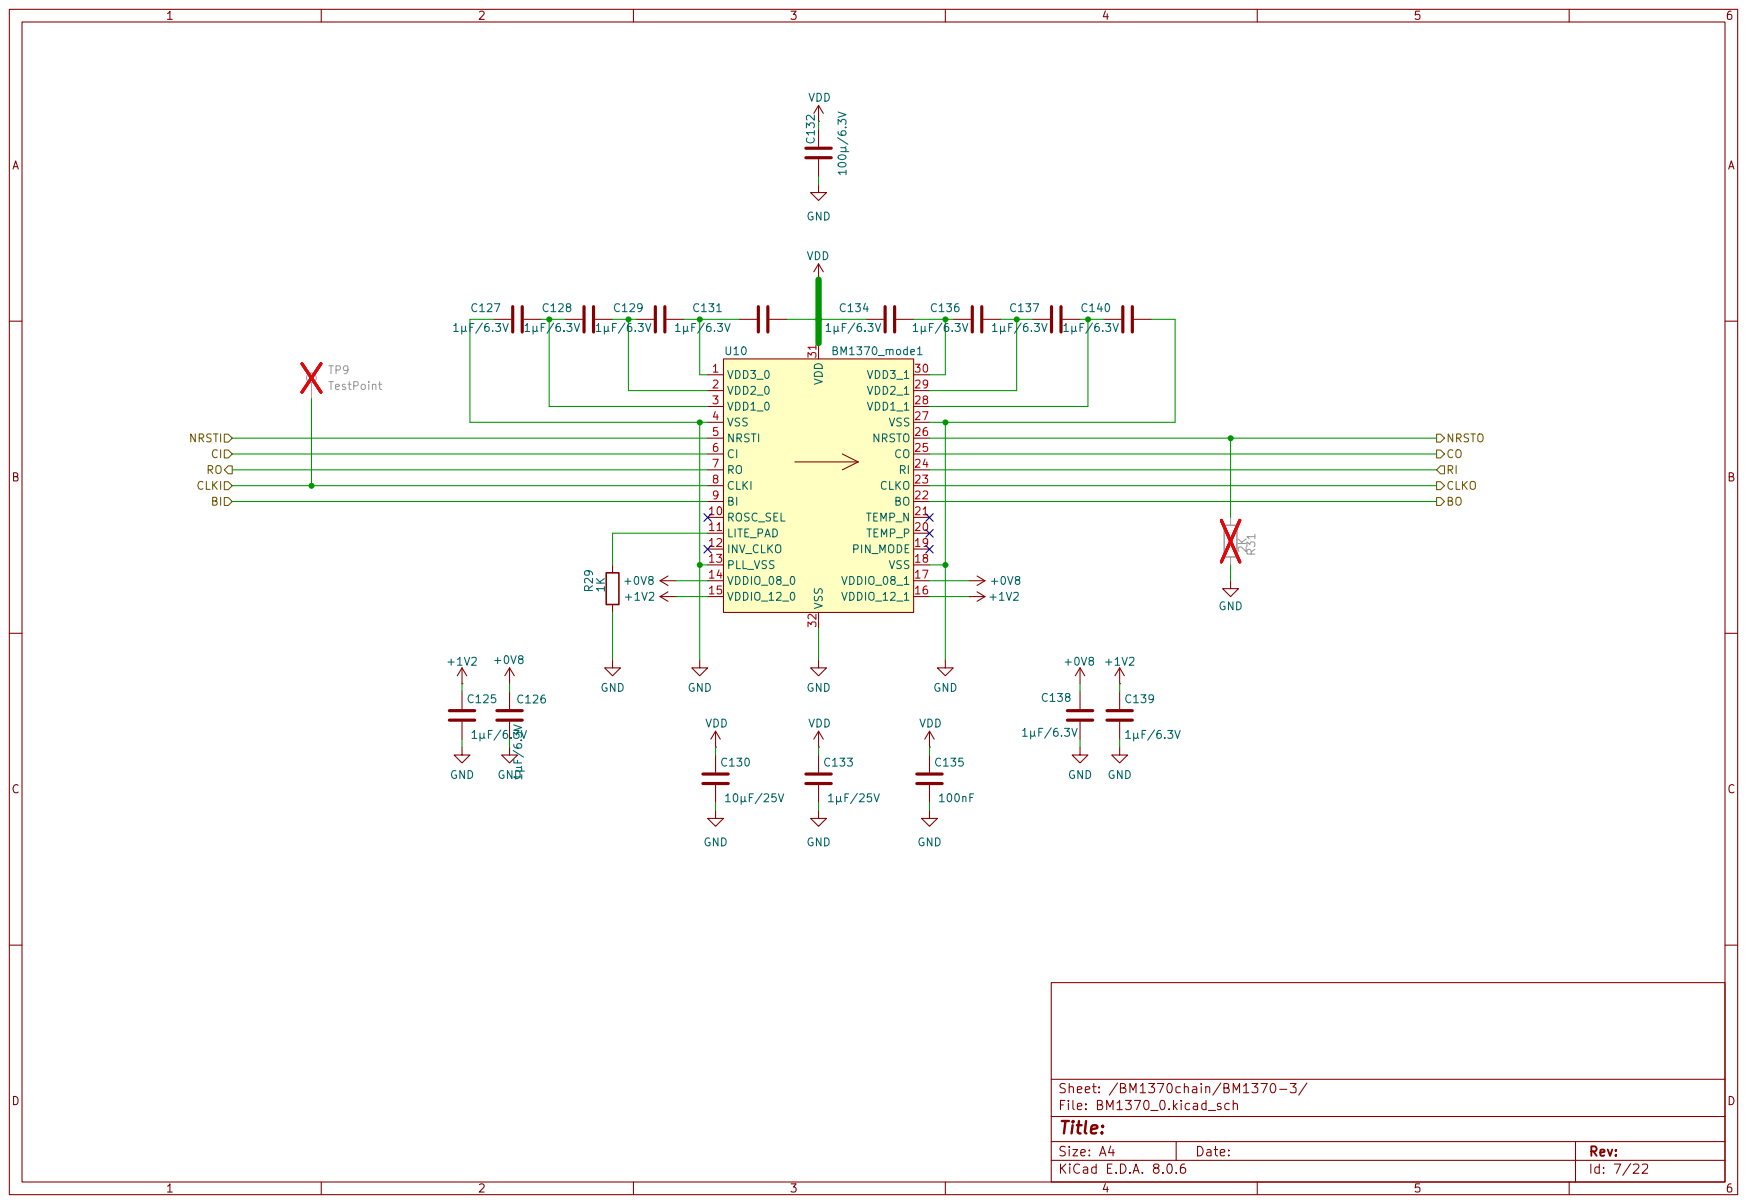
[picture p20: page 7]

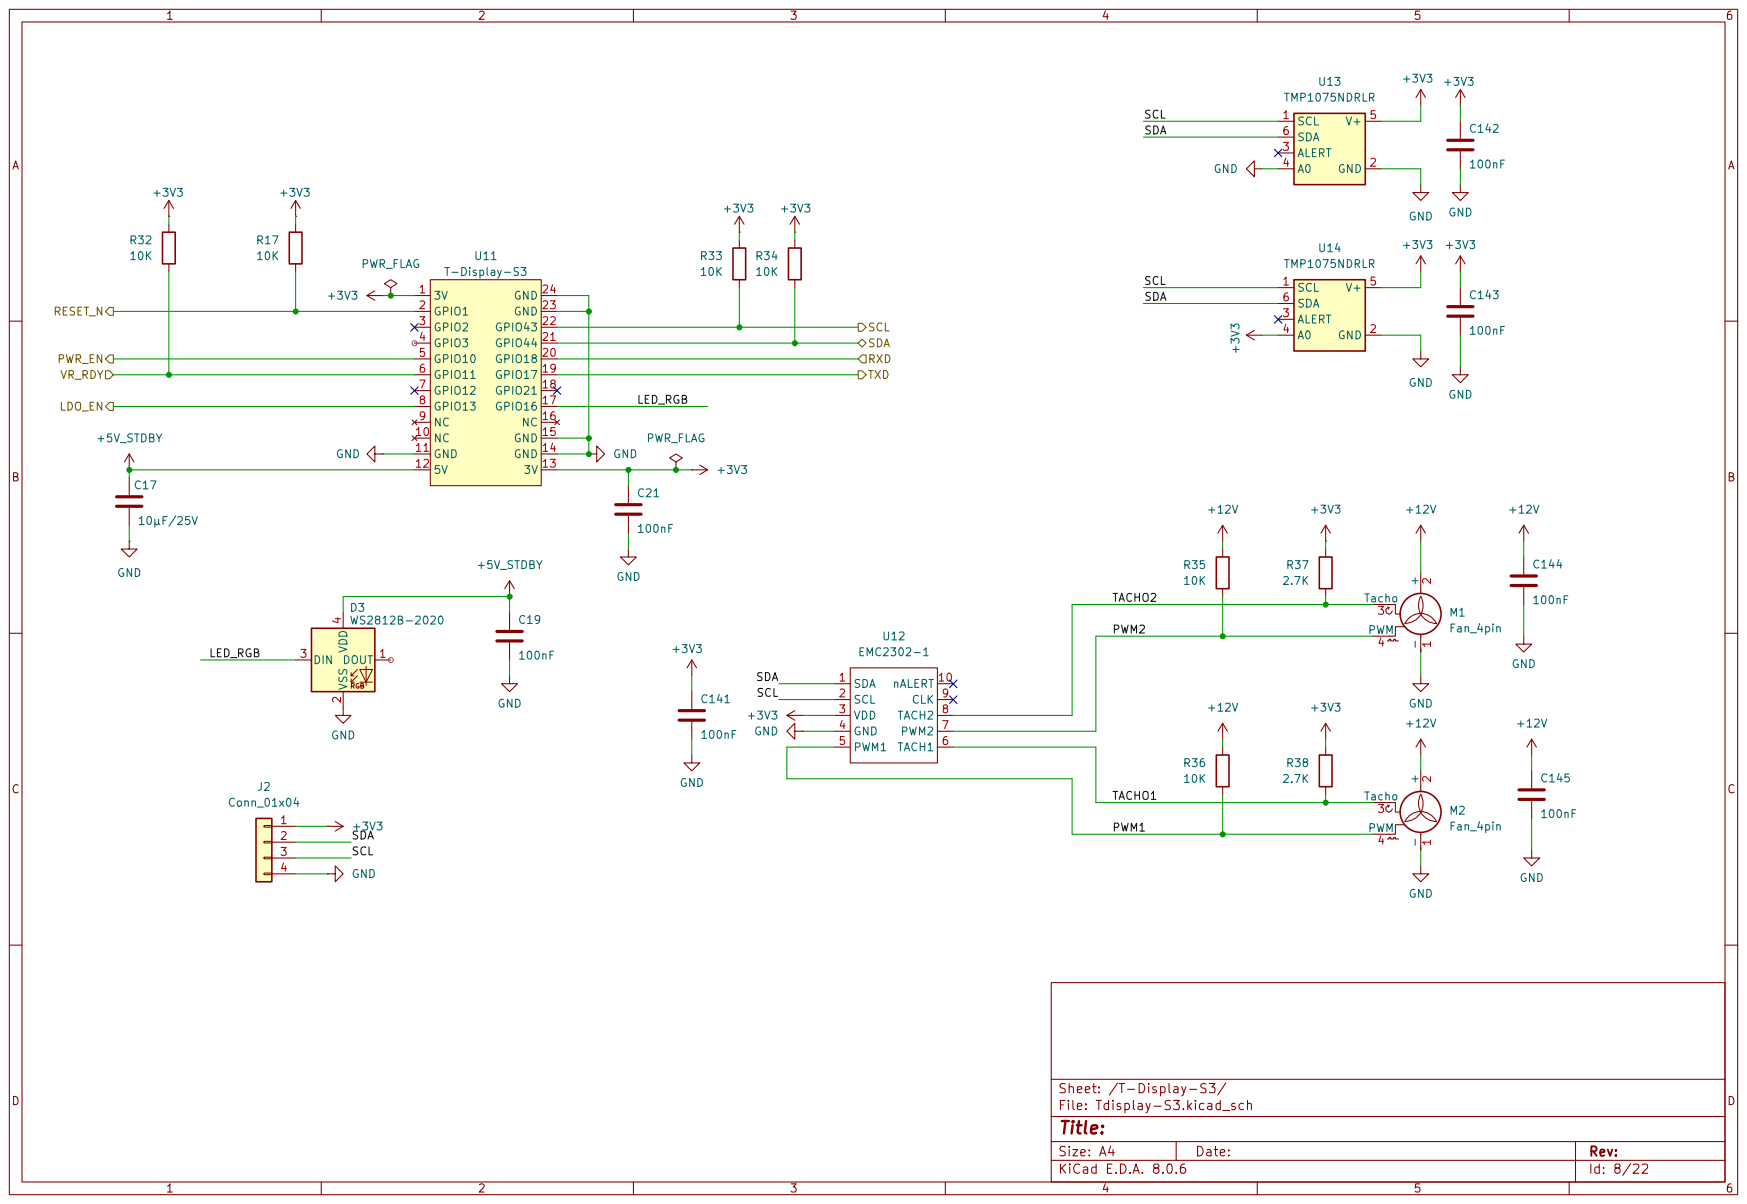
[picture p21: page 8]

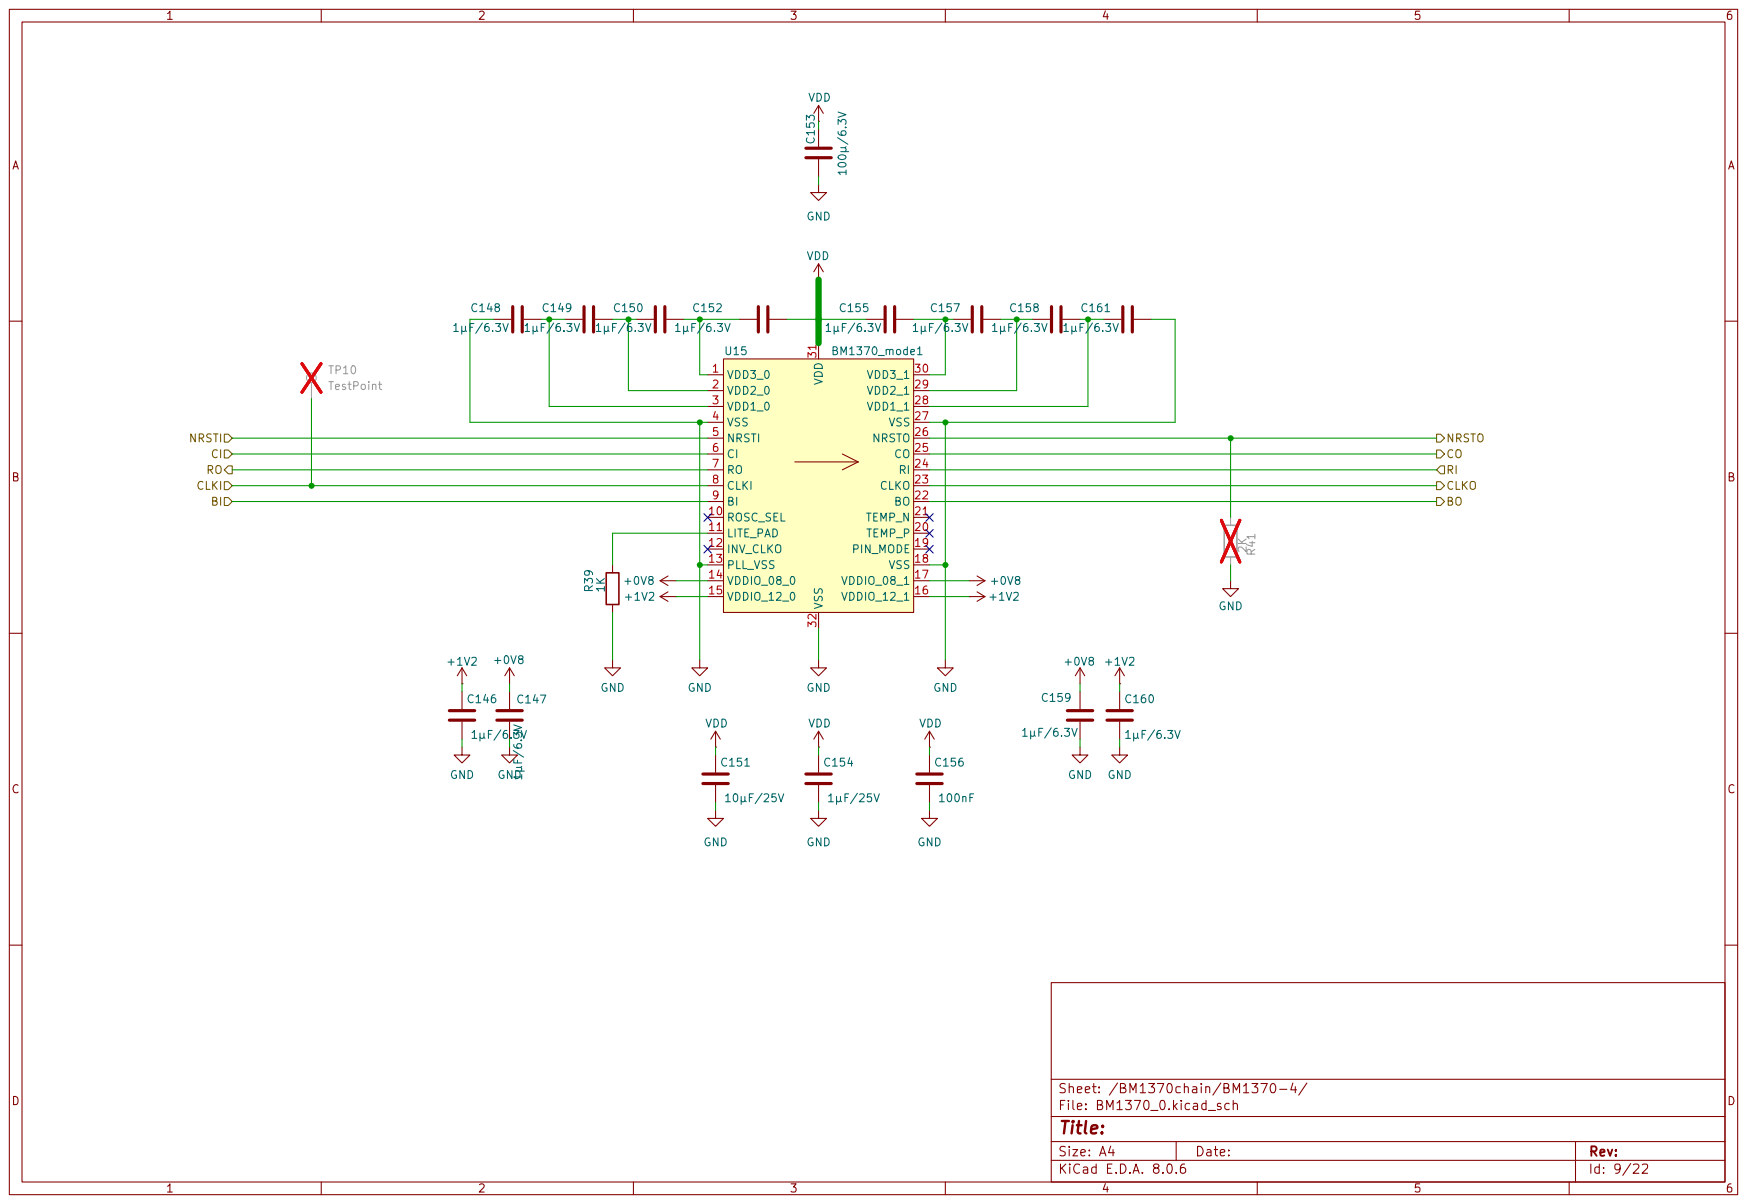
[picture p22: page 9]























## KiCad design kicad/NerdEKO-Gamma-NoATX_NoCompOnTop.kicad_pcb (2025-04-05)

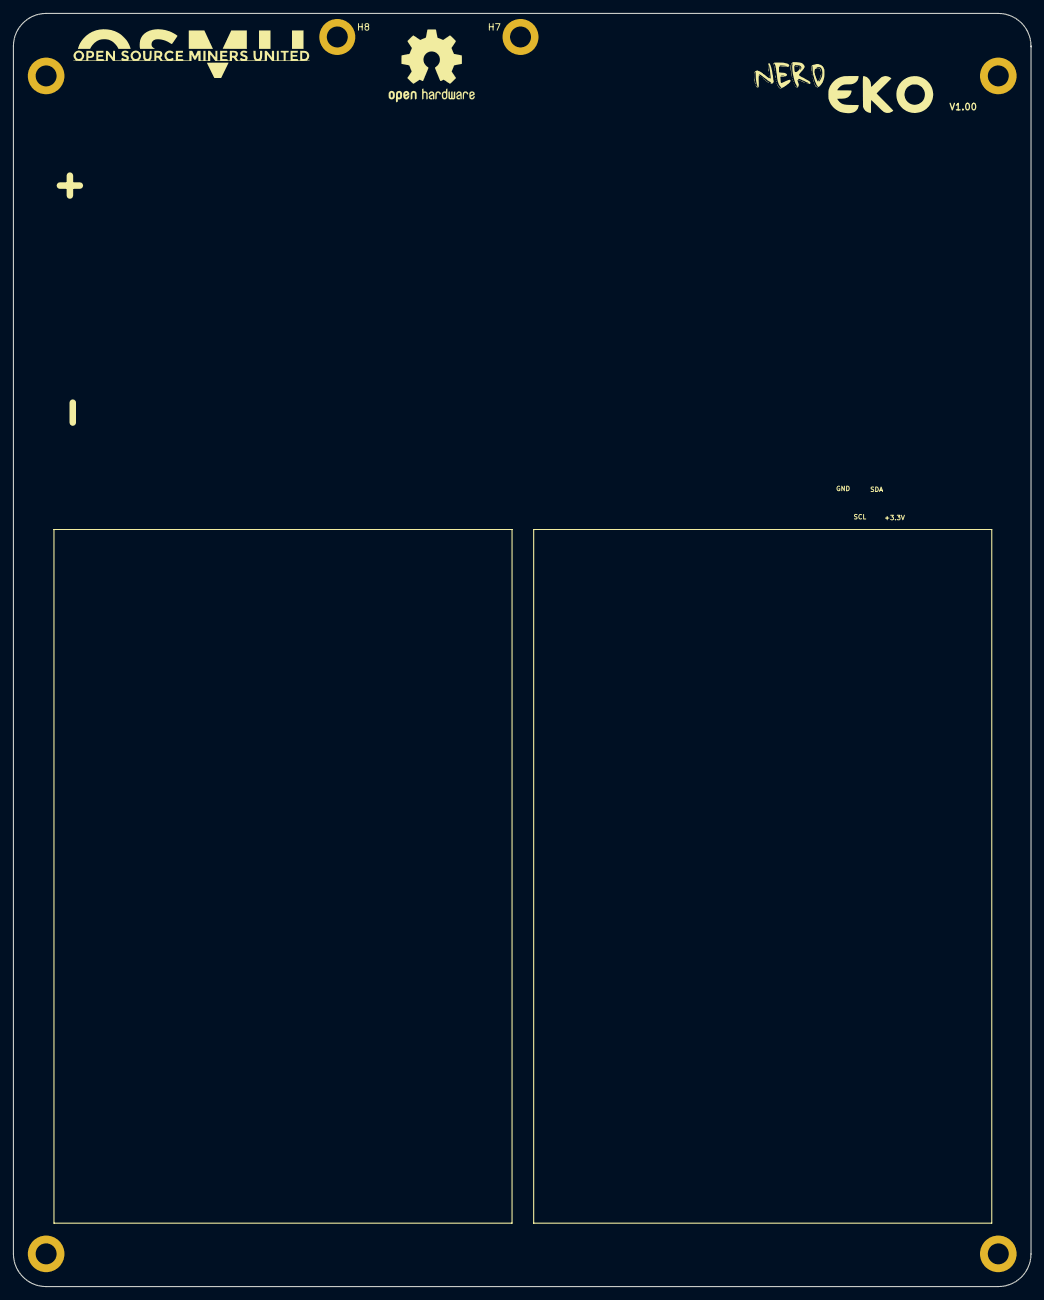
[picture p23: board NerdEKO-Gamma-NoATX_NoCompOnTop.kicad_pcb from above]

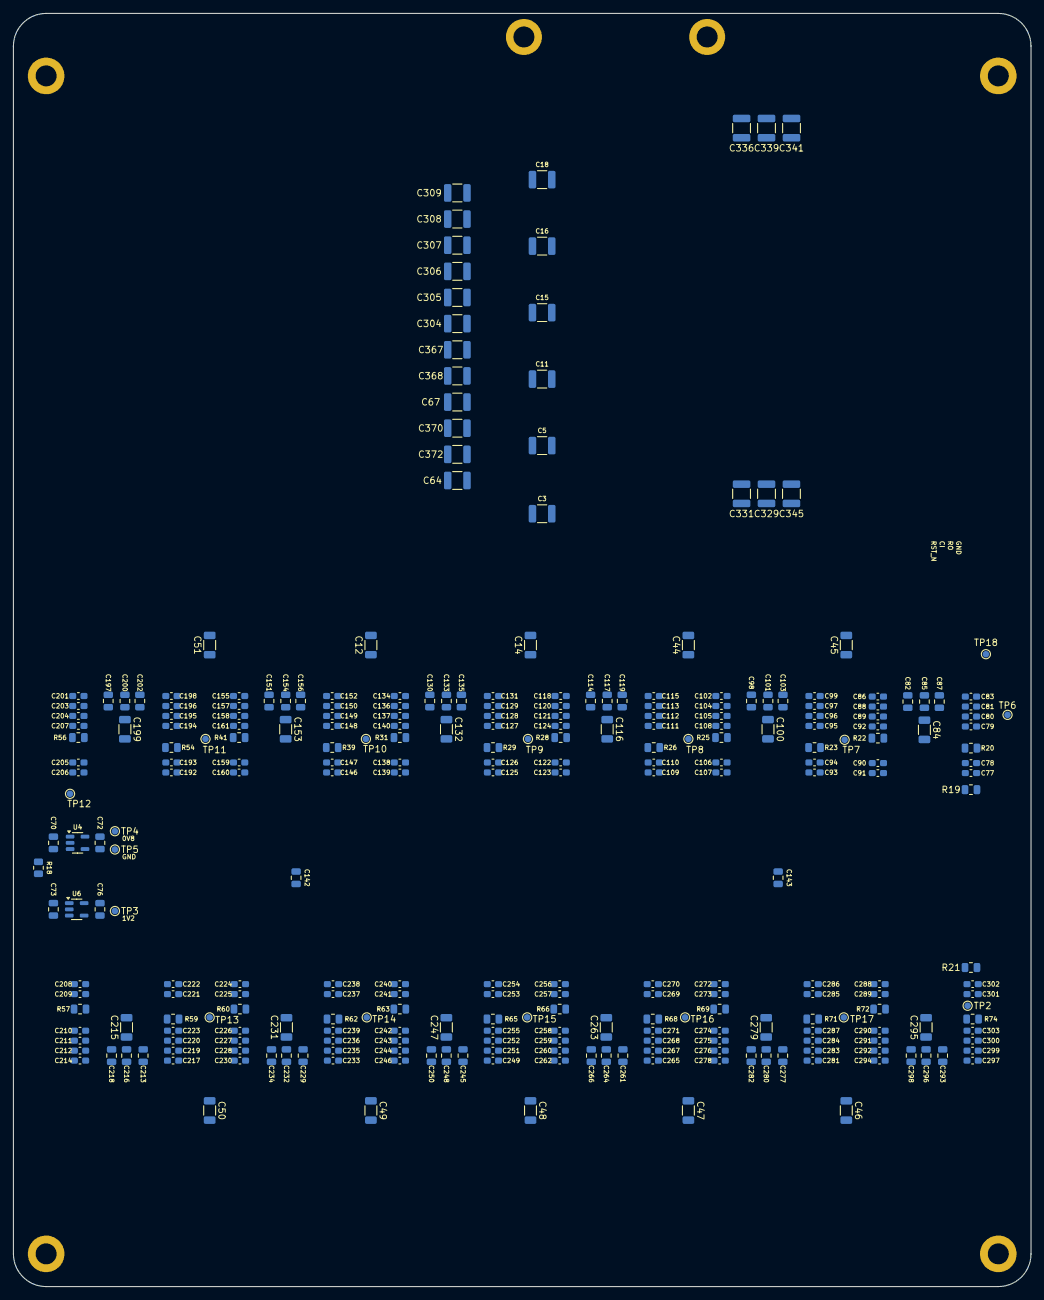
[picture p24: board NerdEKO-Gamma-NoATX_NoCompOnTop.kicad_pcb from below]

Board: 6 copper layers, 155.5 x 194.6 mm, 280 parts (278 on the bottom side), 79 nets.

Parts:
C3, C5, C11, C15, C16, C18, C64, C67, C304, C305, C306, C307, C308, C309, C367, C368, C370, C372: 330µF/4V; C_1210_3225Metric
C12, C14, C44, C45, C46, C47, C48, C49, C50, C51, C84, C100, C116, C132, C153, C199, C215, C231, C247, C263, C279, C295: 100µ/6.3V; C_1206_3216Metric
C70, C73, C87, C103, C119, C135, C142, C143, C156, C202, C218, C234, C250, C266, C282, C298: 100nF; C_0805_2012Metric
C72, C76, C85, C101, C117, C133, C154, C200, C216, C232, C248, C264, C280, C296: 1µF/25V; C_0805_2012Metric
C77, C78, C79, C80, C81, C83, C86, C88, C89, C90, C91, C92, C93, C94, C95, C96, C97, C99, C102, C104, C105, C106, C107, C108, C109, C110, C111, C112, C113, C115, C118, C120, C121, C122, C123, C124, C125, C126, C127, C128, C129, C131, C134, C136, C137, C138, C139, C140, C146, C147, C148, C149, C150, C152, C155, C157, C158, C159, C160, C161, C192, C193, C194, C195, C196, C198, C201, C203, C204, C205, C206, C207, C208, C209, C210, C211, C212, C214, C217, C219, C220, C221, C222, C223, C224, C225, C226, C227, C228, C230, C233, C235, C236, C237, C238, C239, C240, C241, C242, C243, C244, C246, C249, C251, C252, C253, C254, C255, C256, C257, C258, C259, C260, C262, C265, C267, C268, C269, C270, C271, C272, C273, C274, C275, C276, C278, C281, C283, C284, C285, C286, C287, C288, C289, C290, C291, C292, C294, C297, C299, C300, C301, C302, C303: 1µF/6.3V; C_0603_1608Metric_Pad1.08x0.95mm_HandSolder
C82, C98, C114, C130, C151, C197, C213, C229, C245, C261, C277, C293: 10µF/25V; C_0805_2012Metric
C329, C331, C336, C339, C341, C345: 22µ/25V; C_1210_3225Metric
H7, H8: MountingHole; MountingHole_3.2mm_M3_ISO14580_Pad
R18, R19, R21: 10K; R_0805_2012Metric
R20, R23, R26, R29, R39, R54, R57, R60, R63, R66, R69, R72: 1K; R_0805_2012Metric
R22, R25, R28, R31, R41, R56, R59, R62, R65, R68, R71, R74: 2K; R_0805_2012Metric
TP2, TP3, TP4, TP5, TP6, TP7, TP8, TP9, TP10, TP11, TP12, TP13, TP14, TP15, TP16, TP17, TP18: TestPoint; TestPoint_Pad_D1.0mm
U4: MCP1824T-0802E; SOT-23-5
U6: MCP1824T-1202E; SOT-23-5

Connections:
+0V8: C72.1, C78.2, C90.2, C94.2, C106.2, C110.2, C122.2, C126.2, C138.2, C147.2, C159.2, C193.2, C205.2, C209.2, C221.2, C225.2, C237.2, C241.2, C253.2, C257.2, C269.2, C273.2, C285.2, C289.2, C301.2, TP4.1, U4.5 (VOUT)
+1V2: C76.1, C77.1, C91.1, C93.1, C107.1, C109.1, C123.1, C125.1, C139.1, C146.1, C160.1, C192.1, C206.1, C208.1, C222.1, C224.1, C238.1, C240.1, C254.1, C256.1, C270.1, C272.1, C286.1, C288.1, C302.1, R21.2, TP3.1, U6.5 (VOUT)
+3V3: C70.1, C73.1, C142.1, C143.1, U4.1 (VIN), U6.1 (VIN)
+12V: C329.1, C331.1, C336.1, C339.1, C341.1, C345.1
/BM1370chain/LDO_EN: R18.1, U4.3 (EN), U6.3 (EN)
GND: C3.2, C5.2, C11.2, C12.2, C14.2, C15.2, C16.2, C18.2, C44.2, C45.2, C46.2, C47.2, C48.2, C49.2, C50.2, C51.2, C64.2, C67.2, C70.2, C72.2, C73.2, C76.2, C77.2, C78.1, C79.1, C82.2, C84.2, C85.2, C87.2, C90.1, C91.2, C92.2, C93.2, C94.1, C95.1, C98.2, C100.2, C101.2, C103.2, C106.1, C107.2, C108.2, C109.2, C110.1, C111.1, C114.2, C116.2, C117.2, C119.2, C122.1, C123.2, C124.2, C125.2, C126.1, C127.1, C130.2, C132.2, C133.2, C135.2, C138.1, C139.2, C140.2, C142.2, C143.2, C146.2, C147.1, C148.1, C151.2, C153.2, C154.2, C156.2, C159.1, C160.2, C161.2, C192.2, C193.1, C194.1, C197.2, C199.2, C200.2, C202.2, C205.1, C206.2, C207.2, C208.2, C209.1, C210.1, C213.2, C215.2, C216.2, C218.2, C221.1, C222.2, C223.2, C224.2, C225.1, C226.1, C229.2, C231.2, C232.2, C234.2, C237.1, C238.2, C239.2, C240.2, C241.1, C242.1, C245.2, C247.2, C248.2, C250.2, C253.1, C254.2, C255.2, C256.2, C257.1, C258.1, C261.2, C263.2, C264.2, C266.2, C269.1, C270.2, C271.2, C272.2, C273.1, C274.1, C277.2, C279.2, C280.2, C282.2, C285.1, C286.2, C287.2, C288.2, C289.1, C290.1, C293.2, C295.2, C296.2, C298.2, C301.1, C302.2, C303.2, C304.2, C305.2, C306.2, C307.2, C308.2, C309.2, C329.2, C331.2, C336.2, C339.2, C341.2, C345.2, C367.2, C368.2, C370.2, C372.2, R18.2, R19.1, R20.2, R22.1, R23.2, R25.1, R26.2, R28.1, R29.2, R31.1, R39.2, R41.1, R54.2, R56.1, R57.2, R59.1, R60.2, R62.1, R63.2, R65.1, R66.2, R68.1, R69.2, R71.1, R72.2, R74.1, TP5.1, U4.2 (GND), U6.2 (GND)
unnamed: C79.2, C80.1
unnamed: C89.2, C92.1
unnamed: C80.2, C81.1
unnamed: C88.2, C89.1
unnamed: C81.2, C83.1
unnamed: C86.2, C88.1
unnamed: C95.2, C96.1
unnamed: C105.2, C108.1
unnamed: C96.2, C97.1
unnamed: C104.2, C105.1
unnamed: C97.2, C99.1
unnamed: C102.2, C104.1
unnamed: C111.2, C112.1
unnamed: C121.2, C124.1
unnamed: C112.2, C113.1
unnamed: C120.2, C121.1
unnamed: C113.2, C115.1
unnamed: C118.2, C120.1
unnamed: C127.2, C128.1
unnamed: C137.2, C140.1
unnamed: C128.2, C129.1
unnamed: C136.2, C137.1
unnamed: C129.2, C131.1
unnamed: C134.2, C136.1
unnamed: C148.2, C149.1
unnamed: C158.2, C161.1
unnamed: C149.2, C150.1
unnamed: C157.2, C158.1
unnamed: C150.2, C152.1
unnamed: C155.2, C157.1
unnamed: C194.2, C195.1
unnamed: C204.2, C207.1
unnamed: C195.2, C196.1
unnamed: C203.2, C204.1
unnamed: C196.2, C198.1
unnamed: C201.2, C203.1
unnamed: C210.2, C211.1
unnamed: C220.2, C223.1
unnamed: C211.2, C212.1
unnamed: C219.2, C220.1
unnamed: C212.2, C214.1
unnamed: C217.2, C219.1
unnamed: C226.2, C227.1
unnamed: C236.2, C239.1
unnamed: C227.2, C228.1
unnamed: C235.2, C236.1
unnamed: C228.2, C230.1
unnamed: C233.2, C235.1
unnamed: C242.2, C243.1
unnamed: C252.2, C255.1
unnamed: C243.2, C244.1
unnamed: C251.2, C252.1
unnamed: C244.2, C246.1
unnamed: C249.2, C251.1
unnamed: C258.2, C259.1
unnamed: C268.2, C271.1
unnamed: C259.2, C260.1
unnamed: C267.2, C268.1
unnamed: C260.2, C262.1
unnamed: C265.2, C267.1
unnamed: C274.2, C275.1
unnamed: C284.2, C287.1
unnamed: C275.2, C276.1
unnamed: C283.2, C284.1
unnamed: C276.2, C278.1
unnamed: C281.2, C283.1
unnamed: C290.2, C291.1
unnamed: C300.2, C303.1
unnamed: C291.2, C292.1
unnamed: C299.2, C300.1
unnamed: C292.2, C294.1
unnamed: C297.2, C299.1
VDD: C3.1, C5.1, C11.1, C12.1, C14.1, C15.1, C16.1, C18.1, C44.1, C45.1, C46.1, C47.1, C48.1, C49.1, C50.1, C51.1, C64.1, C67.1, C82.1, C83.2, C84.1, C85.1, C86.1, C87.1, C98.1, C99.2, C100.1, C101.1, C102.1, C103.1, C114.1, C115.2, C116.1, C117.1, C118.1, C119.1, C130.1, C131.2, C132.1, C133.1, C134.1, C135.1, C151.1, C152.2, C153.1, C154.1, C155.1, C156.1, C197.1, C198.2, C199.1, C200.1, C201.1, C202.1, C213.1, C214.2, C215.1, C216.1, C217.1, C218.1, C229.1, C230.2, C231.1, C232.1, C233.1, C234.1, C245.1, C246.2, C247.1, C248.1, C249.1, C250.1, C261.1, C262.2, C263.1, C264.1, C265.1, C266.1, C277.1, C278.2, C279.1, C280.1, C281.1, C282.1, C293.1, C294.2, C295.1, C296.1, C297.1, C298.1, C304.1, C305.1, C306.1, C307.1, C308.1, C309.1, C367.1, C368.1, C370.1, C372.1

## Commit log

2024-12-08 first release
    [Assemblage NerdEKO V1.0 with Heatsinks.3MF, BM1370_0.kicad_sch, BM1370_1.kicad_sch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]
2025-04-05 final update
    Version 1.0 : working as expected, 14TH/s
    [Assemblage NerdEKO V1.0 with Heatsinks.3MF, BM1370_0.kicad_sch, BOM NerdEKO-Gamma-NoATX.xlsx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]
